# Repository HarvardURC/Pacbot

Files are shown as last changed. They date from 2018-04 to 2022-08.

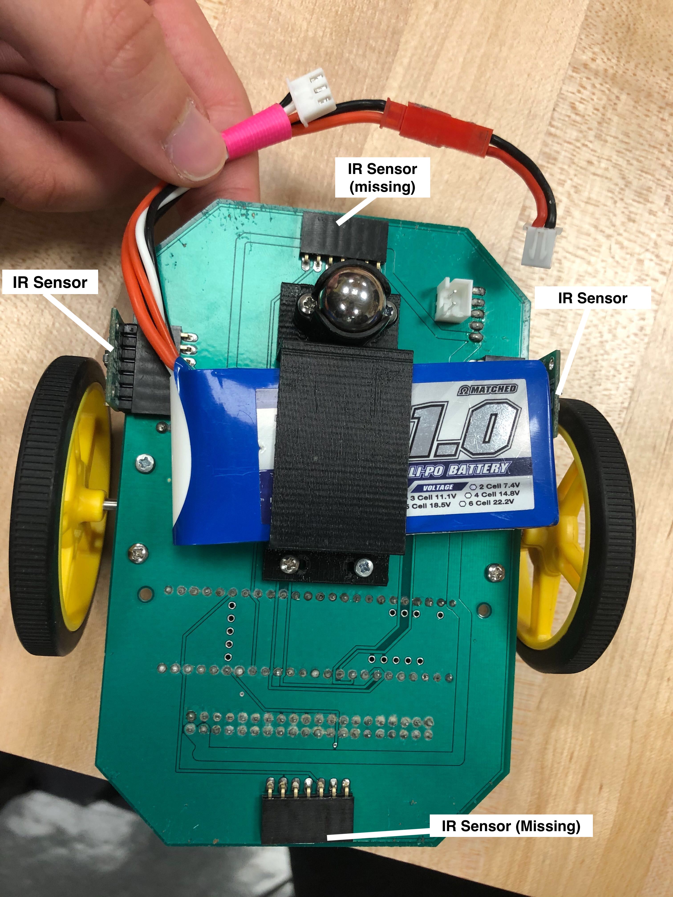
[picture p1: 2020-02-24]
docs/Public Designs/2018-19 Bot/bottomview.jpeg

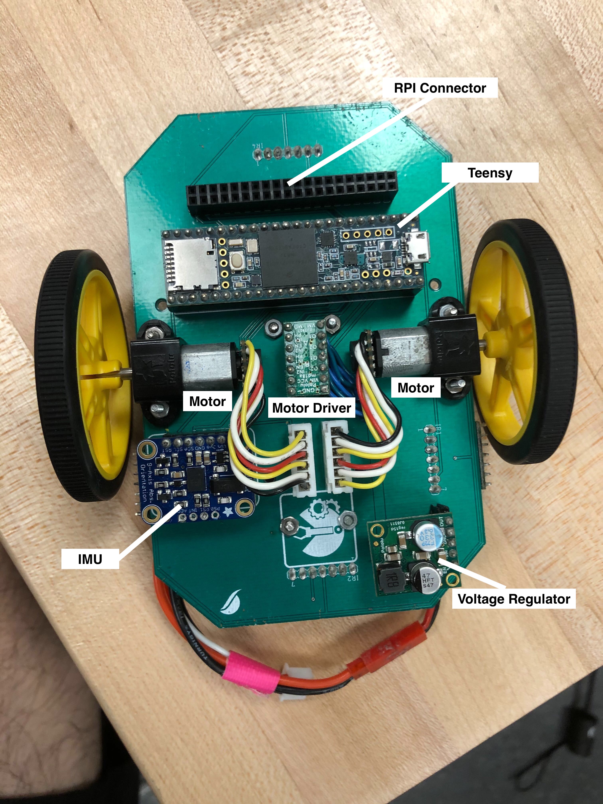
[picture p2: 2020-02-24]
docs/Public Designs/2018-19 Bot/topview.JPG

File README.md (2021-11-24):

# PacBot
Repository for the Harvard Undergraduate Robotics Club's PacBot team

> NOTE: Because this repository includes submodules, it should be cloned using `git clone --recursive`.

The rules for PacBot and helpful images can be found at our website: https://harvardrobotics.com/pacbots

Codebase for 2021-2022 can be found in the ***master*** branch. Codebases for past years can be found in their respective branches.

The current Pacman game code can be found in 'src/gameEngine'. The README there describes how to run the game.

The code for the Harvard robotics team's bot can be found in the 'src/botCode' folder (if you're looking for inspiration).

Documentation for participating teams regarding the game board/arena, bot designs from past years, and how to communicate with the game can be found in the 'docs' directory. Baseline code is provided here that teams can use to code their bots.

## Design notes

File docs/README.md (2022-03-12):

# PacBot Documentation

See 'A Guide to Connecting to the Game' for the step by step process to connect your robot to the PacMan game.

## Arena

'Arena Documentation' contains images of the life sized PacMan game board along with a SLDPRT file containg the CAD design of the arena. Overall, the arena mimics the PacMan game where each path is 7 inches wide. Bots should be smaller than 7 inches by 7 inches to effectively navigate the arena. The arena is currently made of wooden material, and the walls of the channels are painted white.

The arena is programmatically divided into a 28 x 31 grid. The ghost and PacBot locations are read out with respect to this grid. For details on the structure of this grid, 'src/gameEngine/pacbot/grid.py'.

## Sample Bot Code

The PacBot game uses WiFi to send the game state to participating robots; thus all participating teams must have WiFi compatible robots. To do this, PacBot uses Robomodules, a custom Python3 framework for handling communication between modular components using TCP traffic. The game uses a single Robomodules server; teams' bots will connect to this server to receive information about the Pacman game state. Specific documentation for Robomodules can be found here: https://github.com/HarvardURC/robomodules

To connect to the running game engine, teams must run their own Robomodules ProtoModule. The 'Sample BotCode' in this folder contains an example ProtoModule. Please see the 'Sample BotCode' for information regarding the ProtoModule and how it receives the game state.

## Public Designs

The 'Public Designs' folder contains information regarding the EE/ME design of last year's PacBot for the Harvard Undergraduate Robotics Club.

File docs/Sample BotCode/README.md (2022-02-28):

# Sample BotCode

## Files/Folders

### samplePacbotModule.py

This custom module is a subclass of the ProtoModule class from RoboModules. The module is initialized with a connection to the game engine server; the IP address of the game engine server host must be specified via the BIND_ADDRESS environment variable (or by changing the default in the code). Also, your bot must be on the same WiFi network as the game engine server to connect. Make sure this module is also connecting to the correct port the game engine server is listening on via the BIND_PORT environmental variable. 

When an instance of the module is running (by calling the run method), the method msg_received is called whenever the module receives a message from the game engine server. If the msg_type is MsgType.LIGHT_STATE, this message is the game state. This state contains the game state information (as outlined in the rules for the game). If desired, the tick function is helpful for running custom code at a desired frequency (in Hz). More details on how to use Robomodules in your own project if desired can be found in the Robomodules documentation (https://github.com/HarvardURC/robomodules).

### messages

This folder contains the Protobuf definitions of the messages your bot will be receiving. There is no need to edit this code.

### robomodules

Robomodules is a custom Python framework maintained by the Harvard Undergraduate Robotics Club that allows independent modular components to communicate via TCP traffic. The 'samplePacbotModule.py' is one module that communicates with the game engine, another module. No need to edit this code.

## Running the Sample Code

1. Run the game engine.
See 'src/gameEngine' for information. Essentially, one must run 'src/gameEngine/server.py' and 'src/gameEngine/gameEngine.py'.

2. Run 'samplePacbotModule.py'.
The state of the game should be printed on the screen. Make sure the BIND_ADDRESS environment variable is set to the IP address of the game engine server, and make sure the bot is connected to the same WiFi network as the server computer. This can also be run locally along with the game engine; just use the default BIND_ADDRESS of 'localhost'. Finally, make sure the BIND_PORT is the same port that the game engine server is listening on.

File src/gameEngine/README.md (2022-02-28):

# Pacbot 2021-22 gameEngine

## Requirements
To run the gameEngine, the dependencies listed in the ***src/environment.yml*** need to be installed. The ***src/environment.yml*** file is an exported Conda environment, so creating a Conda environment from this is recommended.

Currently, the game engine only runs on **Mac** and **Linux** computers (not Windows). We are working on fixing issues with the Python graphics package to allow the game engine to run on Windows computers.

## Running the gameEngine

To run the gameEngine, first run the server and then run each of the module proccesses separately. 

Specifically, run the following files:

1. `./server.py`
This creates a server for communicating between the different modules. The modules that run the game connect to this server. In addition, the PacBot will connect to this server to receive the game state. The server automatically binds to 'localhost' for testing purposes, but should be bound to the computer's local IP address when attempting to communicate with the robot over WiFi. Set the environment variable BIND_ADDRESS to control the IP address of the server. In addition, a different port may be needed than the default; set the environment variable BIND_PORT to control this as well.

2. `./gameEngine.py`
This runs the game. Type r to restart, p to unpause/pause, and q to quit.

3. `./visualize.py` OR `./terminalPrinter.py`

*visualize.py* displays the game graphics - see **Visualizer** for info regarding its command line arguments.

*terminalPrinter.py* will instead display the game in the terminal.

4. `./keyboardInput.py` OR `./cameraReader.py`

*keyboardInput.py* allows you to provide w,a,s,d commands for moving the PacBot (you must be in this terminal window to provide these commands).

*cameraReader.py* will instead use the connected cameras to track where the PacBot is on the game board and relay that information to the gameEngine.

## Visualizer

The visualizer takes 3 command line arguments:
- `-w` - If this is supplied, then the visualizer will draw the maze walls.
- `-p` - If this is supplied, then the visualizer will draw pacman.
- `-s` - If this is supplied, then the visualizer should fit the entire game onto your computer screen. 
         If not, then you can supply a specific square size by inputting `-s=x`, where x is some integer.
         Default square size without `-s` is 31, square size with `-s` is 25.

## KeyboardInput

When running the keyboard input, you can move pacman using the w,a,s,d keys.

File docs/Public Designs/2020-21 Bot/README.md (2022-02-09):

# Harvard PacBot Design Overview 2020-21
PCB design files and images of the bot can be found in this directory.

## Electrical Components
-1 Raspberry Pi Zero W

-1 Teensy 3.5

-1 PCB

-1 IMU (not in images)

-4 IR Sensors

-2 Magnetic encoder pairs

-2 Motors

-1 Motor Driver

-Li-Po Battery

-1 voltage regulator

(specific links to components can be found at https://docs.google.com/spreadsheets/d/1ZO9OBoGcNkOdx6GaBkAFo6AWodeVCOaCXKic-0er2z0/edit?usp=sharing)

## Mechanical Components
-Wheels/Ball Casters

## Broad Overview
### Sensors

IR sensors are used for detecting whether we are near walls. These are placed on the sides and the front/back of the bot (see photos). Past robots used PID control on these sensors to follow the walls.

Magnetic encoders are attached to the motors to track the amount of distance we travel.

An IMU was intended to be used for general navigation of the robot (to ensure we don't hit walls and turn accurately - other uses are possible). It's not present in the photos.

### Processors

A Raspberry Pi Zero W is used to interface with the motors (through the motor driver) and the IR sensors. It also connects to our local wifi network in order to receive instructions from a computer regarding where the bot should travel (the high level code would run on a remote computer and send commands to the PacBot).

Because of the encoder's output requirements, a Teensy is used to receive the encoder readings. The Teensy is also connected to the IMU. The Teensy communicates these sensor readings to the Raspberry Pi via serial communication.

### Motors

Two medium power, 6V, brushed DC gear motors are used on our bot (see https://www.pololu.com/product/2381). A motor driver is necessary to communicate with the motors from the Raspberry Pi. The encoders are attached to the motors.

### PCB

All of our electrical components are connected via a Printed Circuit Board. This is the main "structure" of our bot; all components are soldered onto this. The KiCad files for the PCB can be found in this directory.

### Code

All of the code for our bot (high level and low level) can be found in the *src/botCode* directory of this GitHub repo.

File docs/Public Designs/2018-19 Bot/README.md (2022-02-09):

# Harvard PacBot Design Overview 2018-19
(PCB design files and schematic can be found in public PacBot Design Folder)

## Electrical Components
-1 Raspberry Pi Zero W

-1 Teensy 3.5

-1 PCB

-1 IMU

-Assorted capacitors, resistors, wires

-4 IR Sensors

-2 Magnetic encoder pairs

-2 Motors

-1 Motor Driver

-Li-Po Battery

(specific links to components can be found at https://docs.google.com/spreadsheets/d/1ZO9OBoGcNkOdx6GaBkAFo6AWodeVCOaCXKic-0er2z0/edit?usp=sharing)

## Mechanical Components
-Wheels/Ball Casters

-3D Printed Battery Clip

## Code
All code can be found in the accompanying folders in this repo. We recommend looking at code from 2018-2019 because this year's code will be undergoing maintenance between now and the competition.

## Broad Overview
As the core processors for the bot, a Raspberry Pi Zero W and Teensy 3.5 were used. Nearly all of our high level and low level code ran off of our Raspberry Pi Zero W; the teensy was mainly used to interface with the encoders and other sensors. The entire bot was centered around the PCB. The motors directly attached to the PCB using small brackets, and all of the electrical components were soldered on in some manner. Although the schematic of the electrical components and the PCB design (which are in this folder) give an idea of the set up of our bot, we unfortunately do not have a SolidWorks design of our 2018-19 bot. A few photos of the 2018-19 bot in this folder help give a picture of the overall design.

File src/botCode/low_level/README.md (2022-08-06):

# Overview of Low Level Code

## teensy_code

This contains code for the teensy. The final code running on the teensy was `teensy_code/sensors/sensors.ino`. Make sure to fulfill the requirements in the requirements.txt file if loading to the teensy. Also, if you're loading this to the teensy on the 2021-2022 bot, you'll need to modify your Teensy Wire library such that Wire1 is defined. Specifically, uncomment `#define WIRE_IMPLEMENT_WIRE1` in WireKinetis.h.

I recommend using TeensyDuino with the teensy. I think these instructions are alright for Teensy: https://www.pjrc.com/teensy/td_usage.html. With the Arduino IDE, make sure you have the correct Board and Port selected under Tools. Also, to load a sketch onto the Teensy, you only need to press the Compile button and the button on the Teensy. DON'T press the Arduino IDE Upload button.

## motors.py

motors.py controls the motors. It uses PIDs of the IMU to turn to the direction we want to go and go straight. directionLowLevelModule.py tells this what direction to take our robot.

## sensors.py and tofSensor.py

These are for controlling our IR sensors.

## teensySensors.py

This is for reading from the serial port to get the Encoder and IMU measurements from the Teensy.

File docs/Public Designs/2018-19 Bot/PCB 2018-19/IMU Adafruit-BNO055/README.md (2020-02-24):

# Adafruit-BNO055-Breakout-PCB
PCB files for the BNO055 Breakout

Format is EagleCAD schematic and board layout

For more details, check out the product page at

    * https://www.adafruit.com/product/2472

Adafruit invests time and resources providing this open source design, 
please support Adafruit and open-source hardware by purchasing 
products from Adafruit!

Designed by Adafruit Industries.  
Creative Commons Attribution, Share-Alike license, check license.txt for more information
All text above must be included in any redistribution

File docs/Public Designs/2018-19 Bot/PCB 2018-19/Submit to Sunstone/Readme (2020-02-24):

LAYER DESCRIPTIONS

tplace (21), tnames (25): Top silk layer

bplace (22), bnames (26): Bottom silk layer

holes (45): Reference for where holes should be placed so that PCB can be fastened by nut and bolt

reference (49): For personal reference (not to be printed)

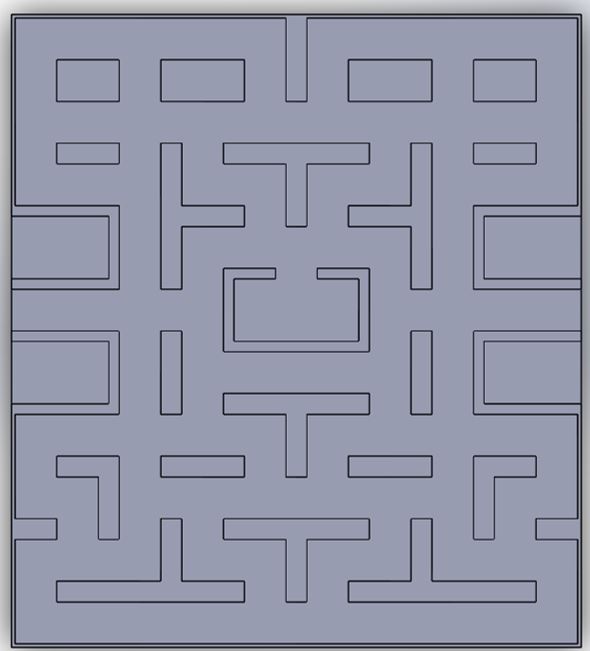
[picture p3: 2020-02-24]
docs/Arena Documentation/Pacbot arena.JPG

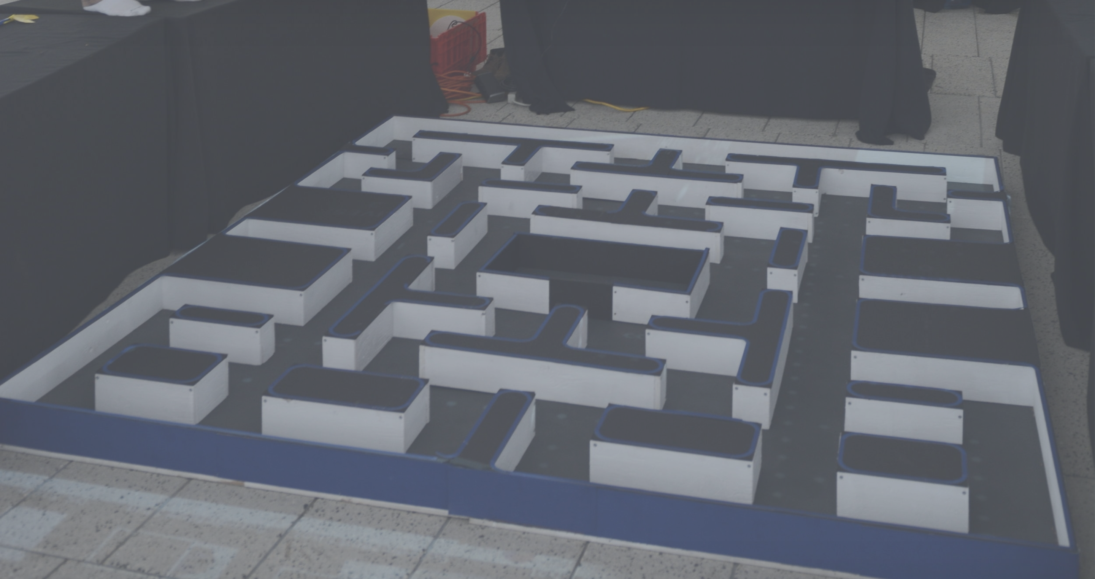
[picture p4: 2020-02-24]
docs/Arena Documentation/arena_side_view.png

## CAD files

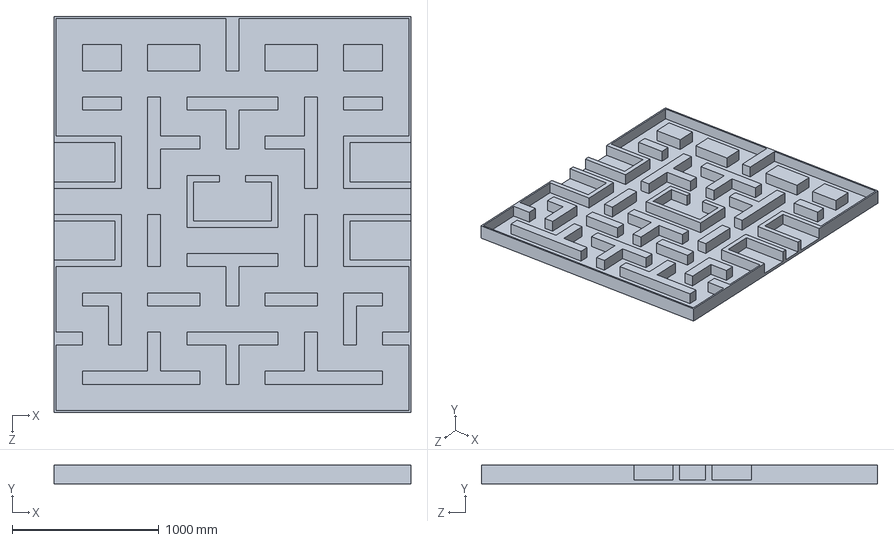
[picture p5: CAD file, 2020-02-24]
docs/Arena Documentation/1classic_arena_pacbot.SLDPRT
2429.9 x 127.0 x 2696.6 mm

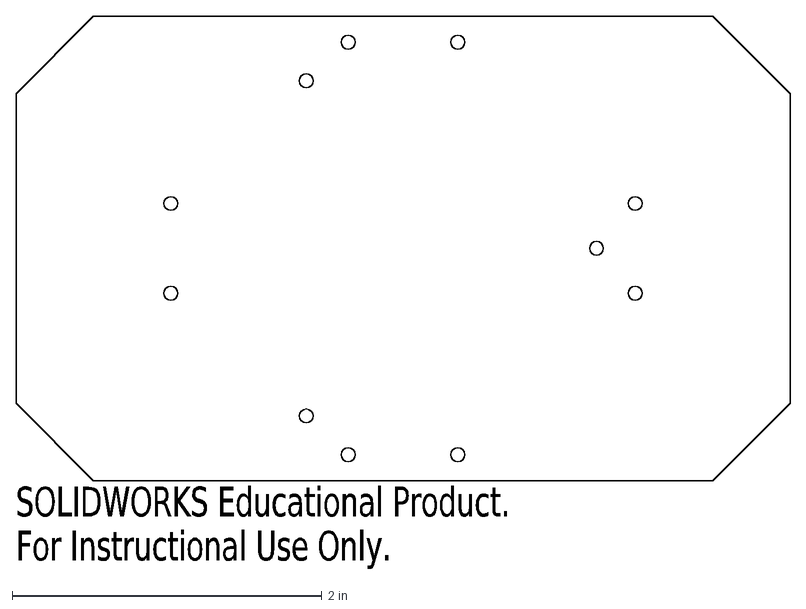
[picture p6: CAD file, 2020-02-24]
docs/Public Designs/2020-21 Bot/PCB/graphics/PacbotPCB.DXF
SOLIDWORKS Educational Product.
For Instructional Use Only.

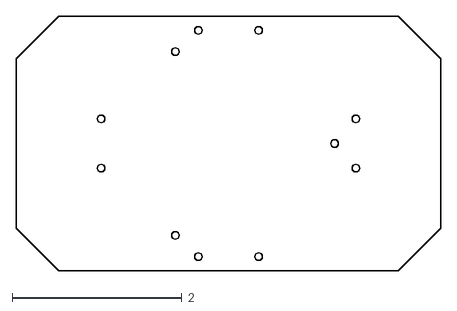
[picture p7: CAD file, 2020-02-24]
docs/Public Designs/2020-21 Bot/PCB/graphics/PacBot_board_outline.dxf
5.00 x 3.00

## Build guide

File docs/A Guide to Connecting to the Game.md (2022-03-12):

# How to run the game and connect to your bot - A Guide

This guide outlines the step by step process for running the PacMan game and connecting your robot to the game.

1. Ensure you have the necessary Python libraries installed as outlined in 'src/requirements.txt'. We recommend using a Conda environment; an image of our environment is provided in 'src/evironment.yml'.

2. Ensure your robot and computer (that's running the PacMan game) are on the same WiFi network.

3. Set the bind address for the PacMan game server.

The computer running the game will have a server that forwards messages about the game state to your robot. The bind address for this server should be the local IP address of your game computer.

Set the bind address via ```export BIND_ADDRESS=myIpAddress``` where ```myIpAddress``` is the local IP address of your game computer. Run this command in your shell on the game computer and on your robot.

4. Run the game on your computer.

Follow the instructions on 'src/gameEngine'. You should specifically run 'src/gameEngine/server.py', 'src/gameEngine/gameEngine.py', and 'src/gameEngine/visualize.py'.

5. Run the sample botcode on your robot.

Run 'docs/Sample BotCode/samplePacbotModule.py' on your robot. The state of the game should be printed.

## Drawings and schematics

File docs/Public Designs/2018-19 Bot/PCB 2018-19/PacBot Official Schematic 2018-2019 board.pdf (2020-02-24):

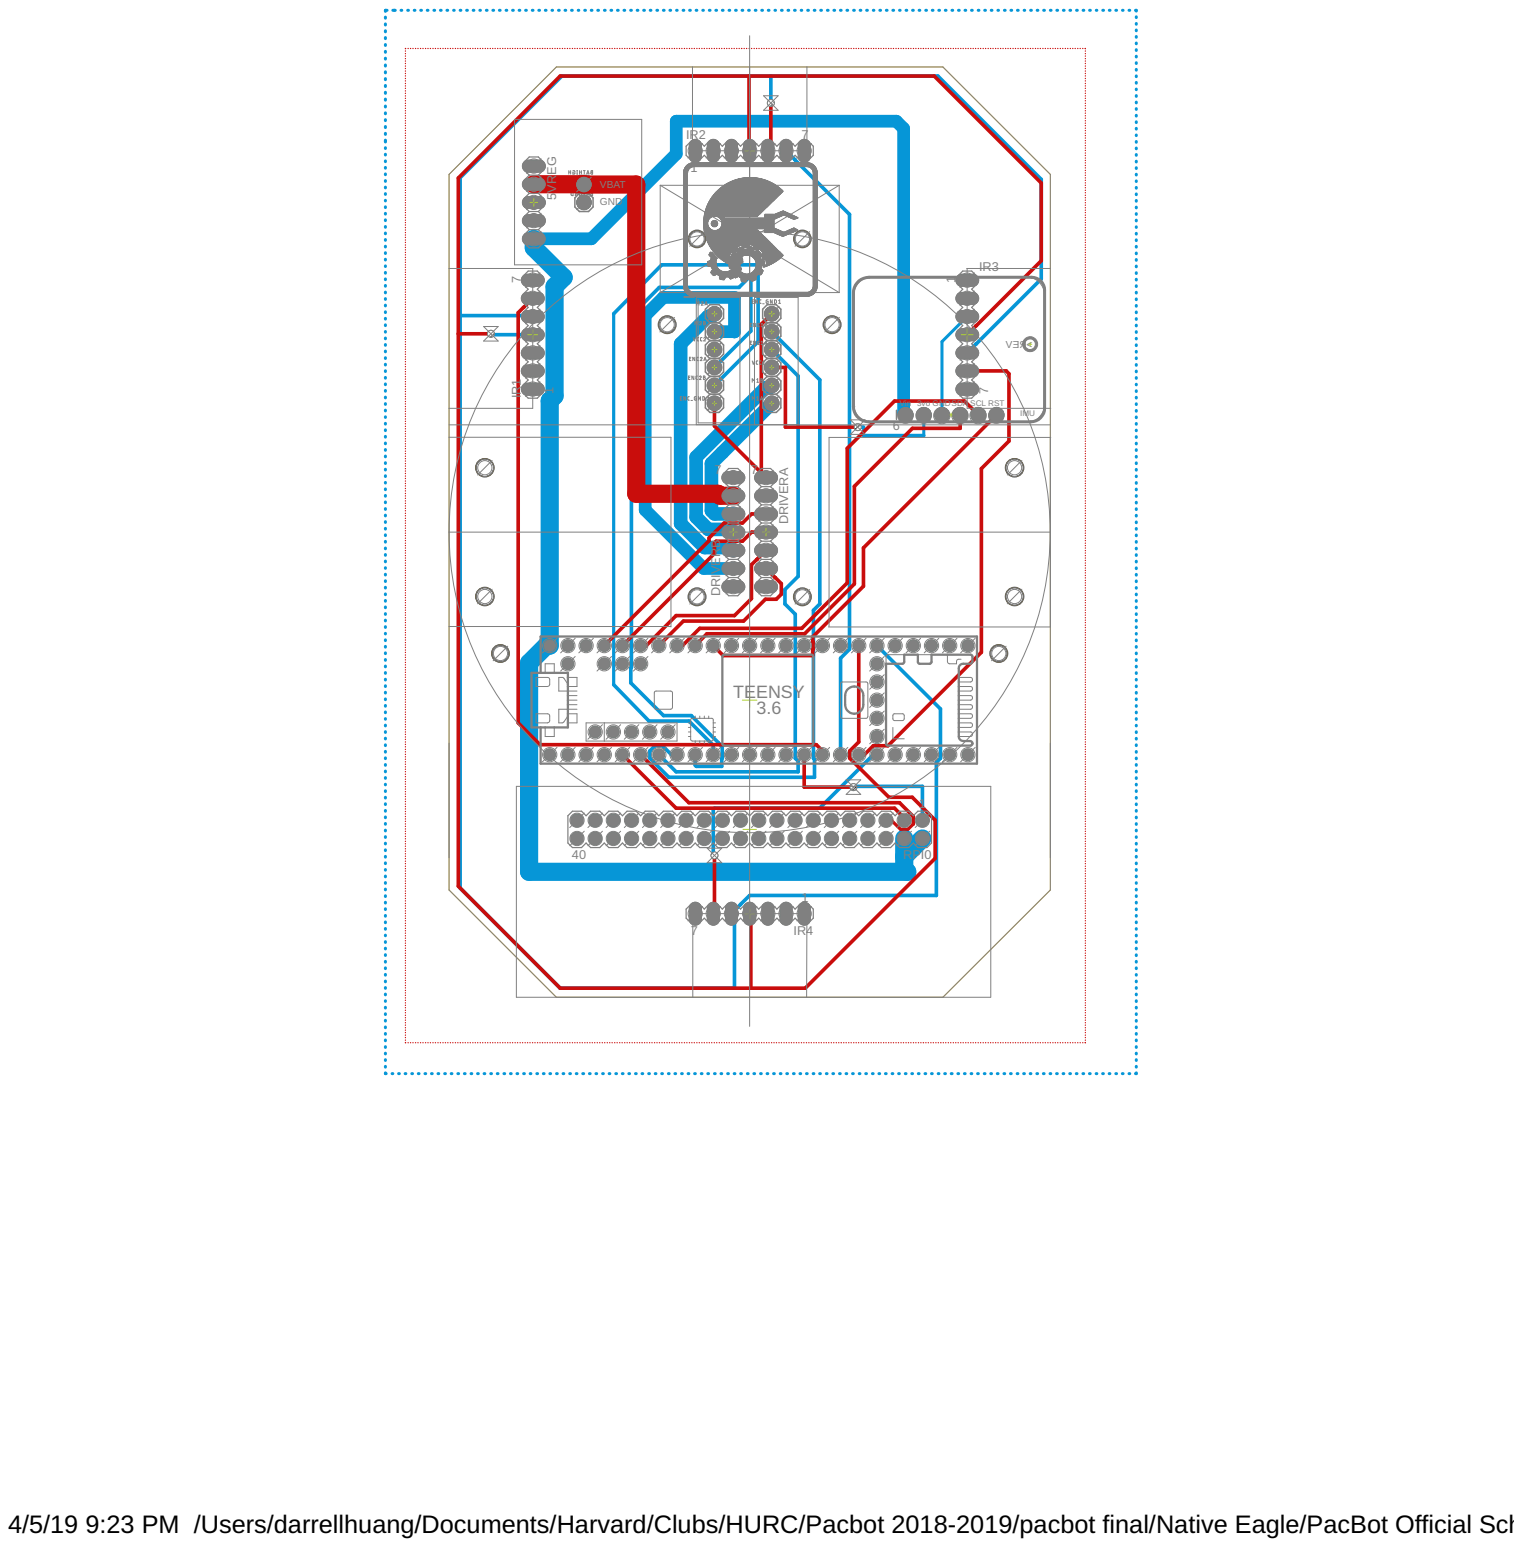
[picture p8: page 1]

Vin 3vo GNDSDA SCL RST 1

4/5/19 9:23 PM /Users/darrellhuang/Documents/Harvard/Clubs/HURC/Pacbot 2018-2019/pacbot final/Native Eagle/PacBot Official Schematic 2018-2019.brd

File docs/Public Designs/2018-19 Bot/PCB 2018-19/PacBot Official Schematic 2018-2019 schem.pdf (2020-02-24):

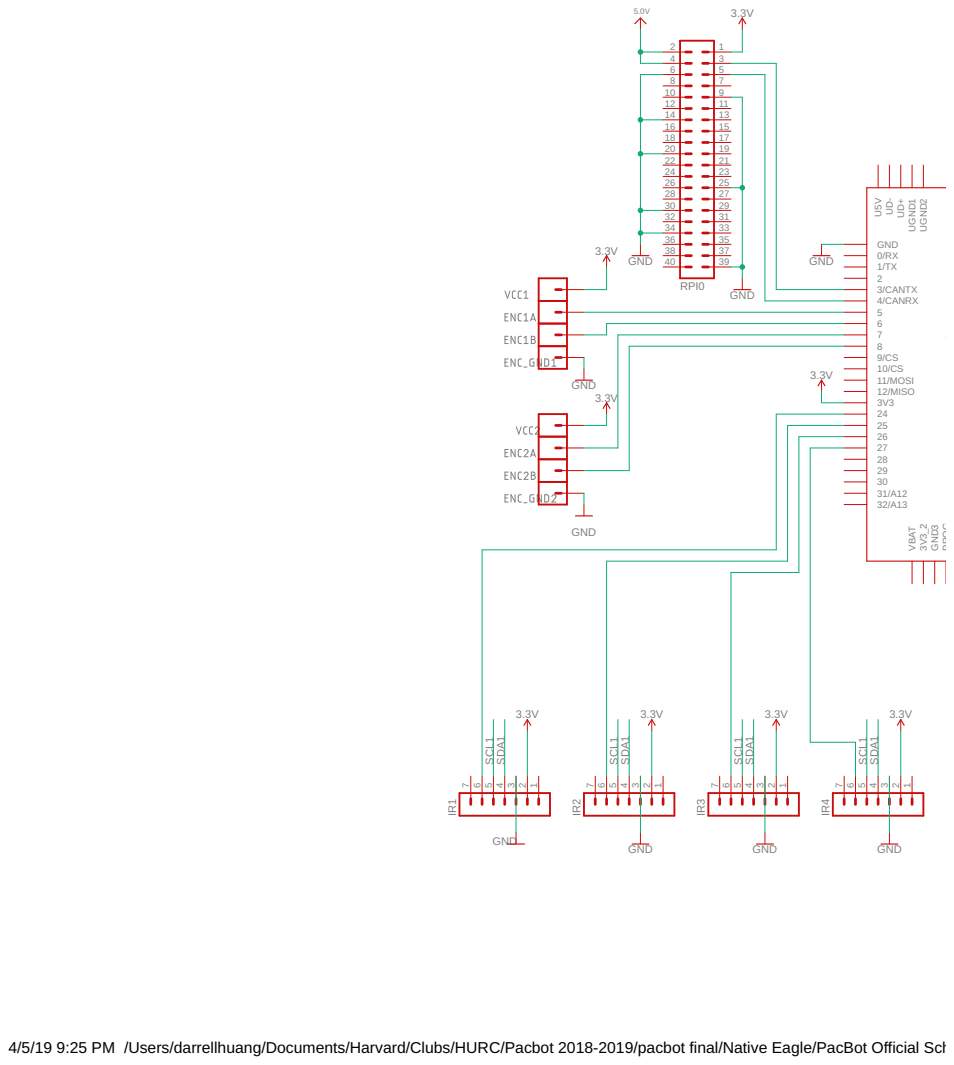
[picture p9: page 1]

4/5/19 9:25 PM /Users/darrellhuang/Documents/Harvard/Clubs/HURC/Pacbot 2018-2019/pacbot final/Native Eagle/PacBot Official Schematic 2018-2019.sch (Sheet: 1/1)

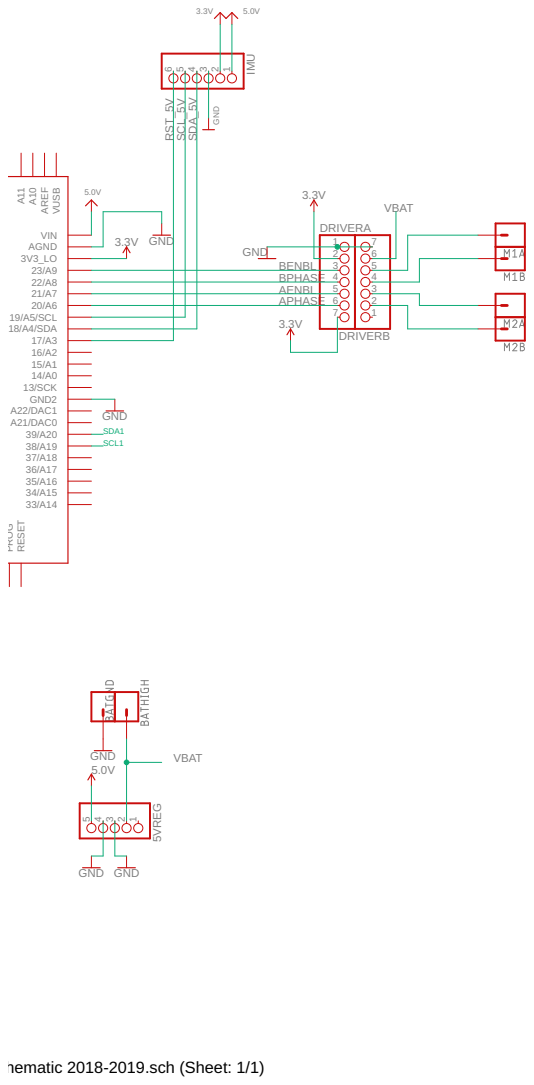
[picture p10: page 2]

BPHASE | 4
AENBL | 5
APHASE | 6

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

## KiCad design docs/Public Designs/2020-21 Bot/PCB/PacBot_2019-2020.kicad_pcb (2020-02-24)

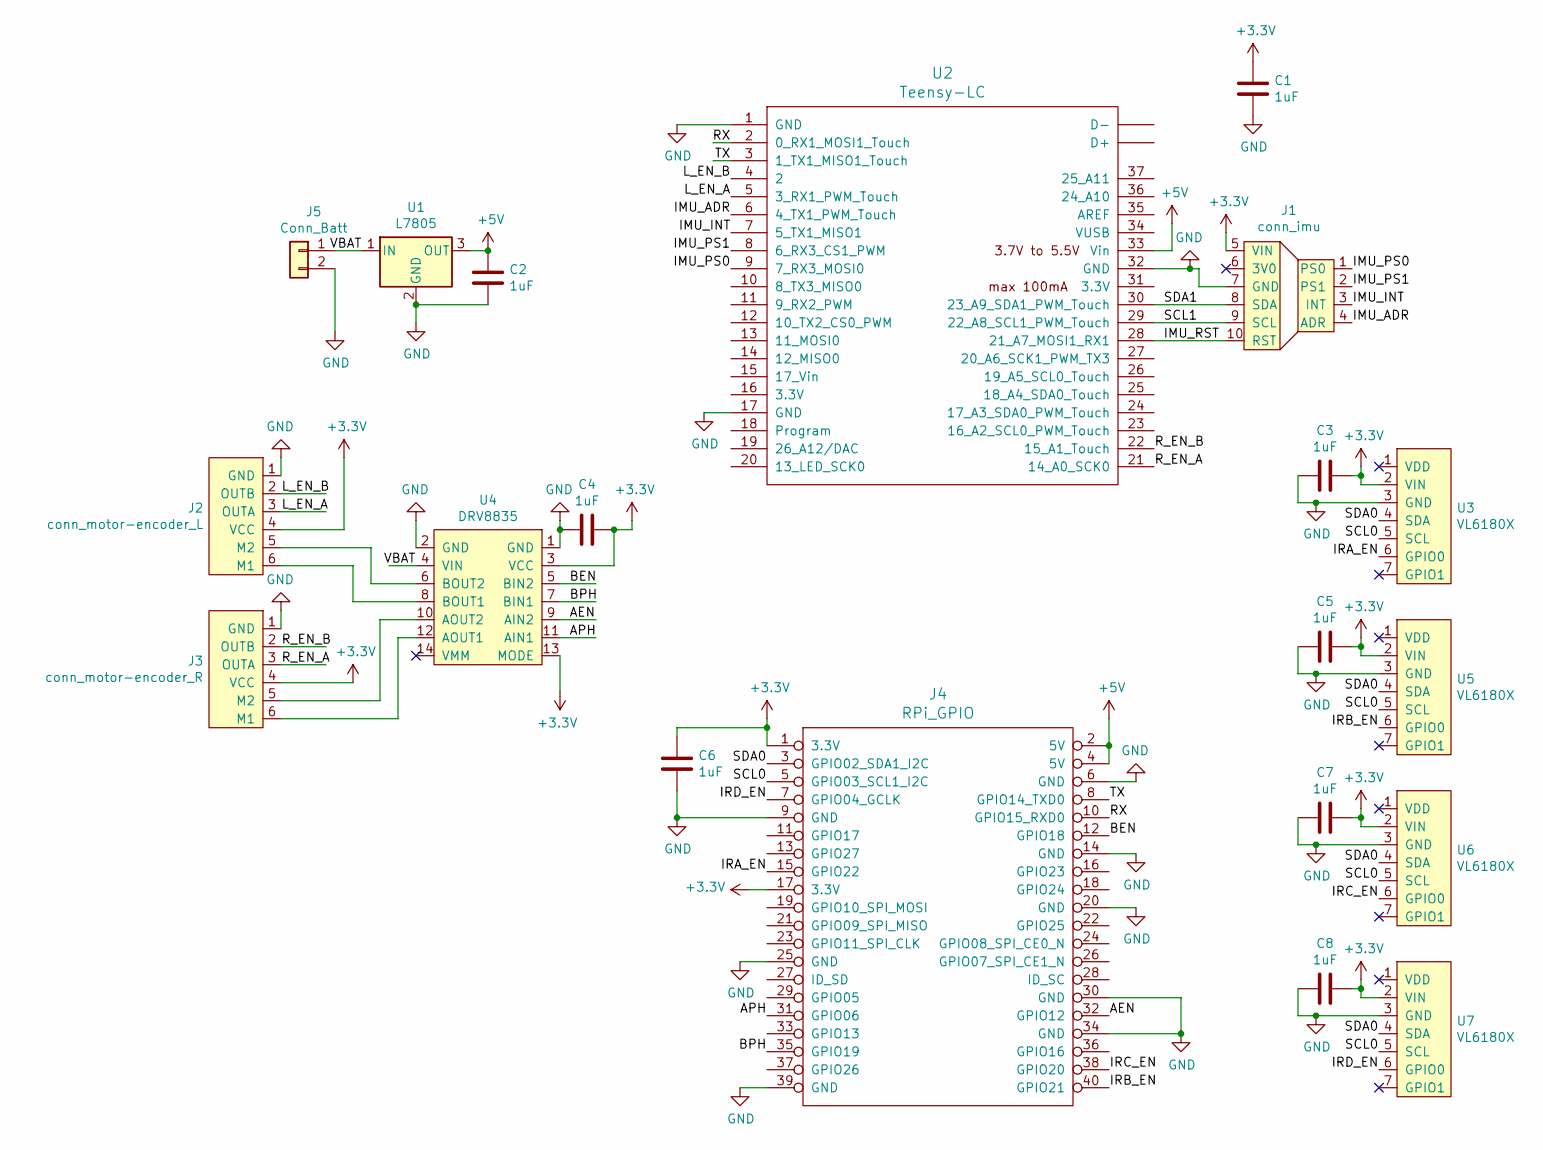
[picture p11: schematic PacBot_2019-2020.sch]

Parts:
C1, C2, C3, C4, C5, C6, C7, C8: 1uF; C_0603_1608Metric
J1: conn_imu
J2: conn_motor-encoder_L; JST_PH_B6B-PH-K_1x06_P2.00mm_Vertical
J3: conn_motor-encoder_R; JST_PH_B6B-PH-K_1x06_P2.00mm_Vertical
J4: RPi_GPIO; ADA3708_RPI-ZERO
J5: Conn_Batt; JST_PH_B2B-PH-K_1x02_P2.00mm_Vertical
U1: L7805; Stocko_MKS_1653-6-0-303_1x3_P2.50mm_Vertical
U2: Teensy-LC; Teensy30_31_32_LC
U3, U5, U6, U7: VL6180X; conn_ir
U4: DRV8835; drv8835

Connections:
+3V3: C1.1, C3.2, C4.1, C5.1, C6.1, C7.1, C8.1, J1.5 (VIN), J2.4 (VCC), J3.4 (VCC), J4.1 (3.3V), J4.17 (3.3V), U3.2 (VIN), U4.3 (VCC), U4.13 (MODE), U5.2 (VIN), U6.2 (VIN), U7.2 (VIN)
+5V: C2.1, J4.2 (5V), J4.4 (5V), U1.3 (OUT), U2.33 (Vin)
/AEN: J4.32 (GPIO12), U4.9 (AIN2)
/APH: J4.31 (GPIO06), U4.11 (AIN1)
/BEN: J4.12 (GPIO18), U4.5 (BIN2)
/BPH: J4.35 (GPIO19), U4.7 (BIN1)
/IMU_ADR: J1.4 (ADR), U2.6 (4_TX1_PWM_Touch)
/IMU_INT: J1.3 (INT), U2.7 (5_TX1_MISO1)
/IMU_PS0: J1.1 (PS0), U2.9 (7_RX3_MOSI0)
/IMU_PS1: J1.2 (PS1), U2.8 (6_RX3_CS1_PWM)
/IMU_RST: J1.10 (RST), U2.28 (21_A7_MOSI1_RX1)
/IRA_EN: J4.15 (GPIO22), U3.6 (GPIO0)
/IRB_EN: J4.40 (GPIO21), U5.6 (GPIO0)
/IRC_EN: J4.38 (GPIO20), U6.6 (GPIO0)
/IRD_EN: J4.7 (GPIO04_GCLK), U7.6 (GPIO0)
/L_EN_A: J2.3 (OUTA), U2.5 (3_RX1_PWM_Touch)
/L_EN_B: J2.2 (OUTB), U2.4 (2)
/RX: J4.10 (GPIO15_RXD0), U2.2 (0_RX1_MOSI1_Touch)
/R_EN_A: J3.3 (OUTA), U2.21 (14_A0_SCK0)
/R_EN_B: J3.2 (OUTB), U2.22 (15_A1_Touch)
/SCL0: J4.5 (GPIO03_SCL1_I2C), U3.5 (SCL), U5.5 (SCL), U6.5 (SCL), U7.5 (SCL)
/SCL1: J1.9 (SCL), U2.29 (22_A8_SCL1_PWM_Touch)
/SDA0: J4.3 (GPIO02_SDA1_I2C), U3.4 (SDA), U5.4 (SDA), U6.4 (SDA), U7.4 (SDA)
/SDA1: J1.8 (SDA), U2.30 (23_A9_SDA1_PWM_Touch)
/TX: J4.8 (GPIO14_TXD0), U2.3 (1_TX1_MISO1_Touch)
/VBAT: J5.1, U1.1 (IN), U4.4 (VIN)
GND: C1.2, C2.2, C3.1, C4.2, C5.2, C6.2, C7.2, C8.2, J1.7 (GND), J2.1 (GND), J3.1 (GND), J4.6 (GND), J4.9 (GND), J4.14 (GND), J4.20 (GND), J4.25 (GND), J4.30 (GND), J4.34 (GND), J4.39 (GND), J5.2, U1.2 (GND), U2.1 (GND), U2.17 (GND), U2.32 (GND), U3.3 (GND), U4.1 (GND), U4.2 (GND), U5.3 (GND), U6.3 (GND), U7.3 (GND)
unnamed: J2.5 (M2), U4.6 (BOUT2)
unnamed: J2.6 (M1), U4.8 (BOUT1)
unnamed: J3.5 (M2), U4.10 (AOUT2)
unnamed: J3.6 (M1), U4.12 (AOUT1)

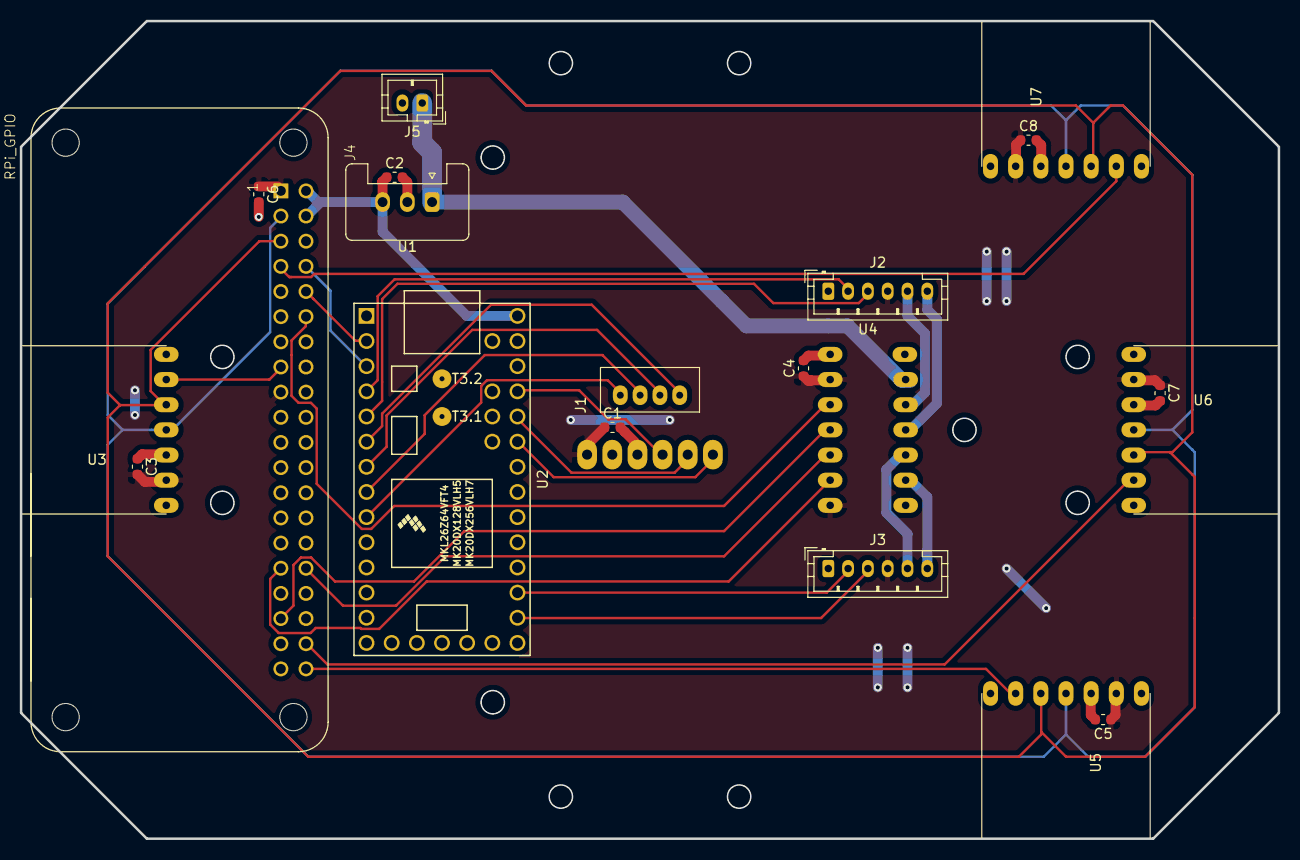
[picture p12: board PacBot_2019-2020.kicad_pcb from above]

Board: 2 copper layers, 127.0 x 82.6 mm, 20 parts (0 on the bottom side), 31 nets.

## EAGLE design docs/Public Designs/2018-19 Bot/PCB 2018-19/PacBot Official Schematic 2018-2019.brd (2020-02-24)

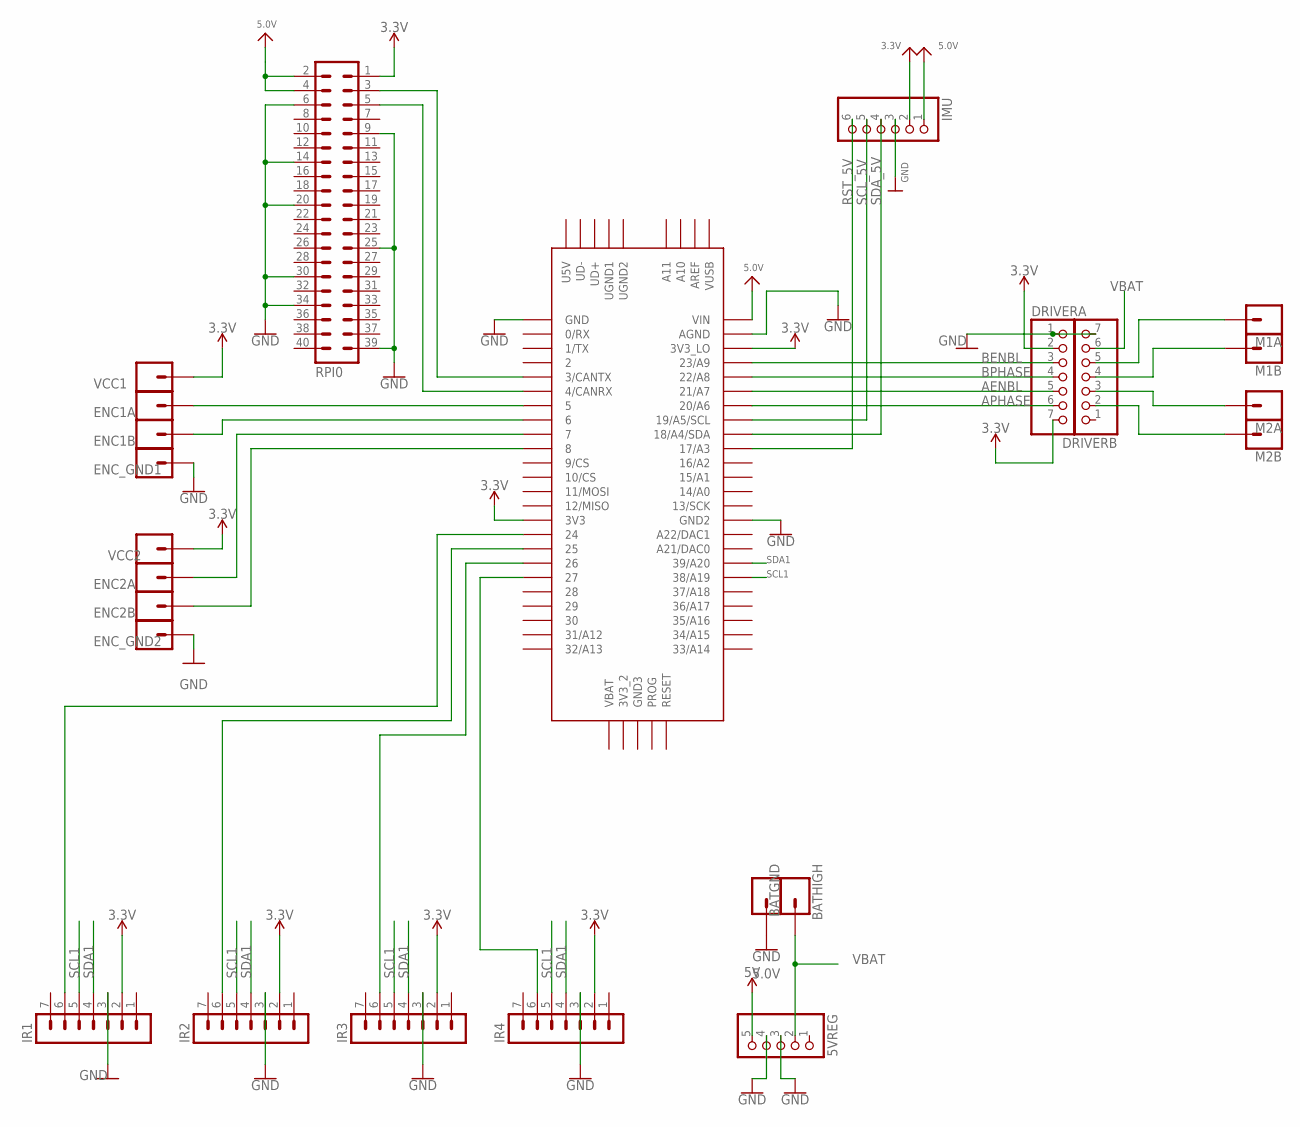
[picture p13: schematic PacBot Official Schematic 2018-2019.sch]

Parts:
5VREG: PINHD-1X5; 1X05
BATGND: CONN_01; 1X01
BATHIGH: CONN_01; 1X01
DRIVERA: PINHD-1X7; 1X07
DRIVERB: PINHD-1X7; 1X07
ENC1A, ENC1B, ENC2A, ENC2B: CONN_01; 1X01
ENC_GND1, ENC_GND2: CONN_01; 1X01
IMU: HEADER-1X676MIL; 1X06_ROUND_76
IR1, IR2, IR3, IR4: MA07-1
M1A, M1B, M2A, M2B: CONN_01; 1X01
RPI0: MA20-2
U$1: TEENSY_3.5/3.6
VCC1, VCC2: CONN_01; 1X01

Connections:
3.3V: DRIVERA.2, DRIVERA.7, IMU.2, IR1.2, IR2.2, IR3.2, IR4.2, RPI0.1, U$1.3V3, U$1.3V3_LO, VCC1.1, VCC2.1
5.0V: 5VREG.5, IMU.1, RPI0.2, RPI0.4, U$1.VIN
AENBL: DRIVERA.5, U$1.21/A7
APHASE: DRIVERA.6, U$1.20/A6
BENBL: DRIVERA.3, U$1.23/A9
BPHASE: DRIVERA.4, U$1.22/A8
GND: 5VREG.3, 5VREG.4, BATGND.1, DRIVERA.1, DRIVERB.7, ENC_GND1.1, ENC_GND2.1, IMU.3, IR1.3, IR2.3, IR3.3, IR4.3, RPI0.6, RPI0.9, RPI0.14, RPI0.20, RPI0.25, RPI0.30, RPI0.34, RPI0.39, U$1.AGND, U$1.GND, U$1.GND2
unnamed: ENC1A.1, U$1.5
unnamed: IR2.6, U$1.25
unnamed: RPI0.3, U$1.3/CANTX
unnamed: IR3.6, U$1.26
unnamed: ENC1B.1, U$1.6
unnamed: RPI0.5, U$1.4/CANRX
unnamed: IR4.6, U$1.27
unnamed: DRIVERB.5, M1A.1
unnamed: DRIVERB.4, M1B.1
unnamed: DRIVERB.3, M2A.1
unnamed: DRIVERB.2, M2B.1
unnamed: ENC2A.1, U$1.7
unnamed: ENC2B.1, U$1.8
unnamed: IR1.6, U$1.24
RST_5V: IMU.6, U$1.17/A3
SCL1: IR1.5, IR2.5, IR3.5, IR4.5, U$1.38/A19
SCL_5V: IMU.5, U$1.19/A5/SCL
SDA1: IR1.4, IR2.4, IR3.4, IR4.4, U$1.39/A20
SDA_5V: IMU.4, U$1.18/A4/SDA
VBAT: 5VREG.2, BATHIGH.1, DRIVERB.6

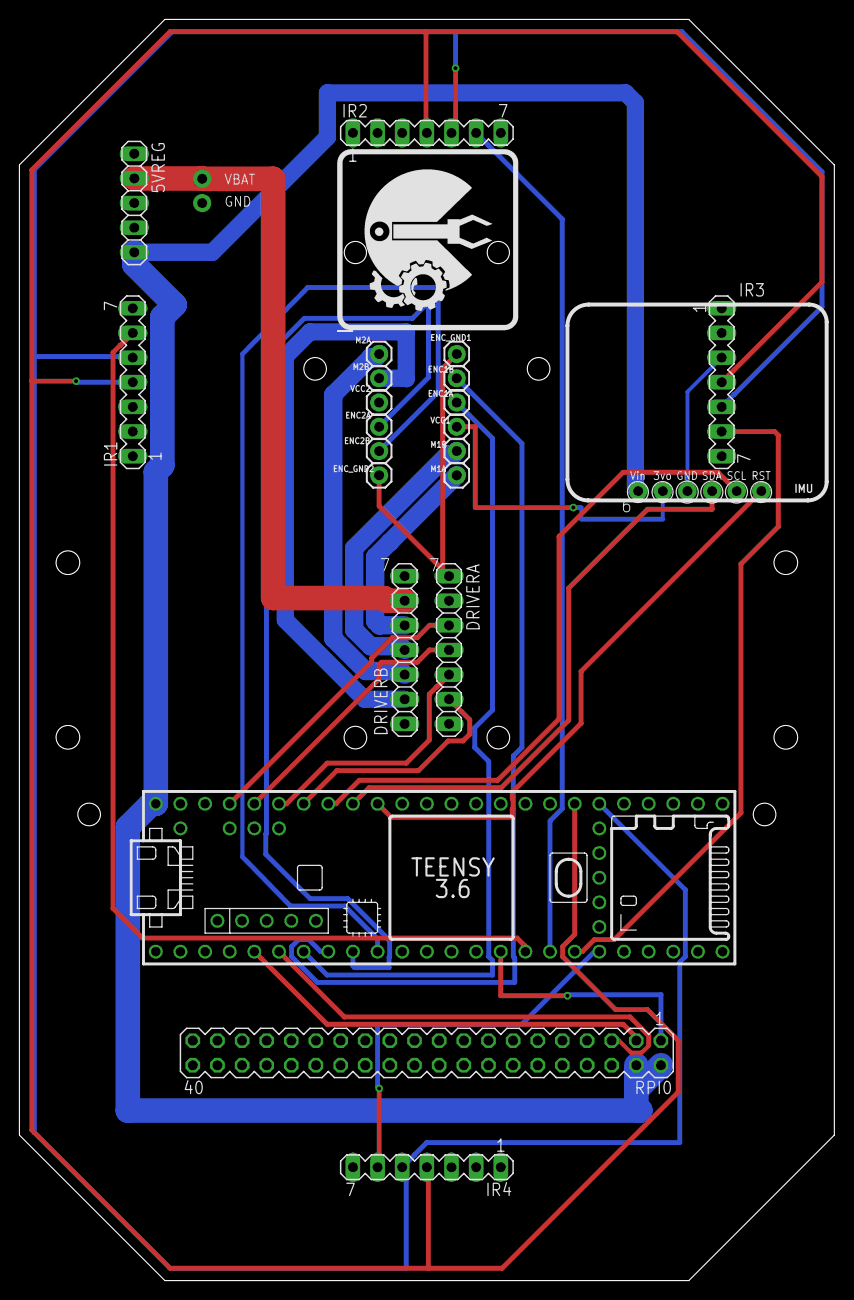
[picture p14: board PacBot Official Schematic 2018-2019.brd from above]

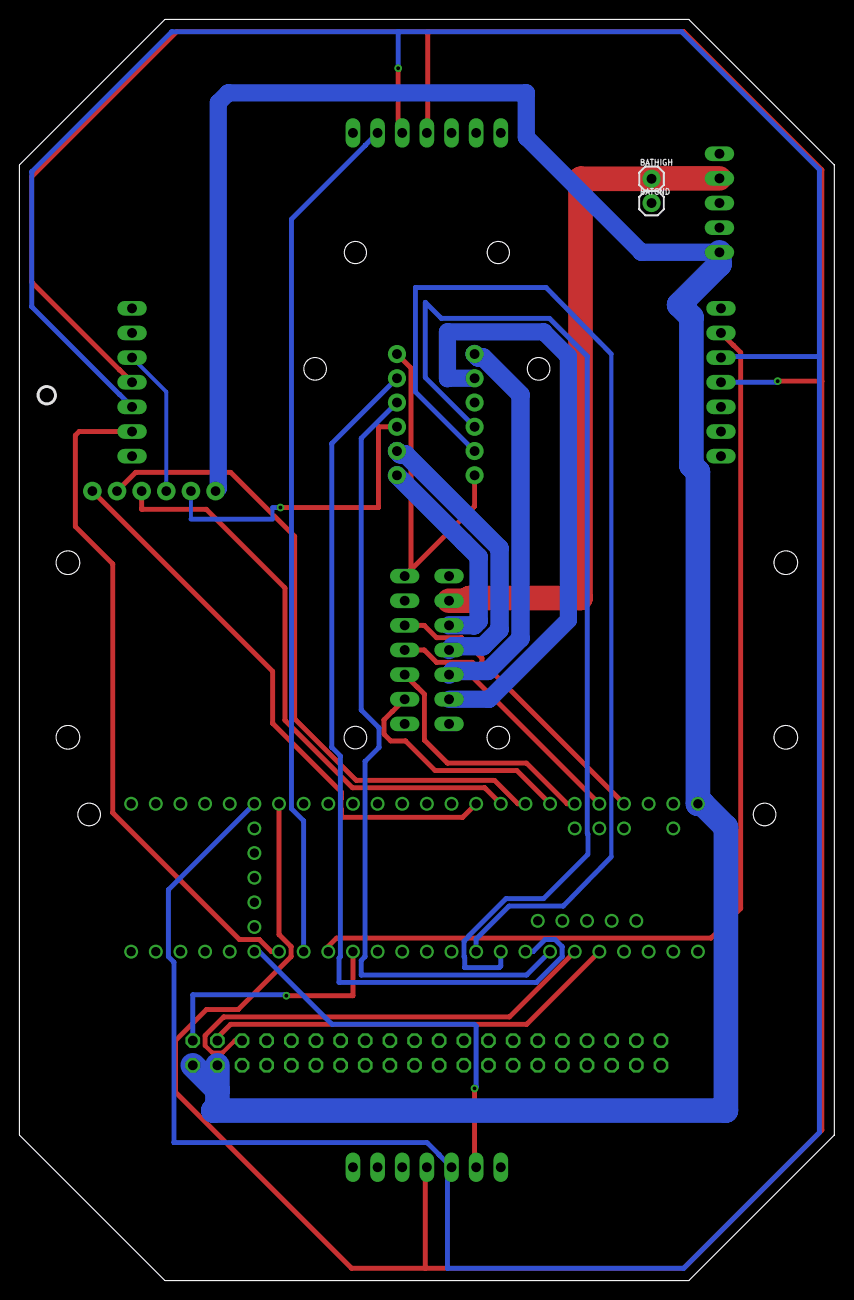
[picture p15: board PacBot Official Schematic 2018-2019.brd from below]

Board: 2 copper layers, 84.0 x 130.0 mm, 25 parts (3 on the bottom side), 27 nets.

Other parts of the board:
U$65: PCBFEAT-REV-040

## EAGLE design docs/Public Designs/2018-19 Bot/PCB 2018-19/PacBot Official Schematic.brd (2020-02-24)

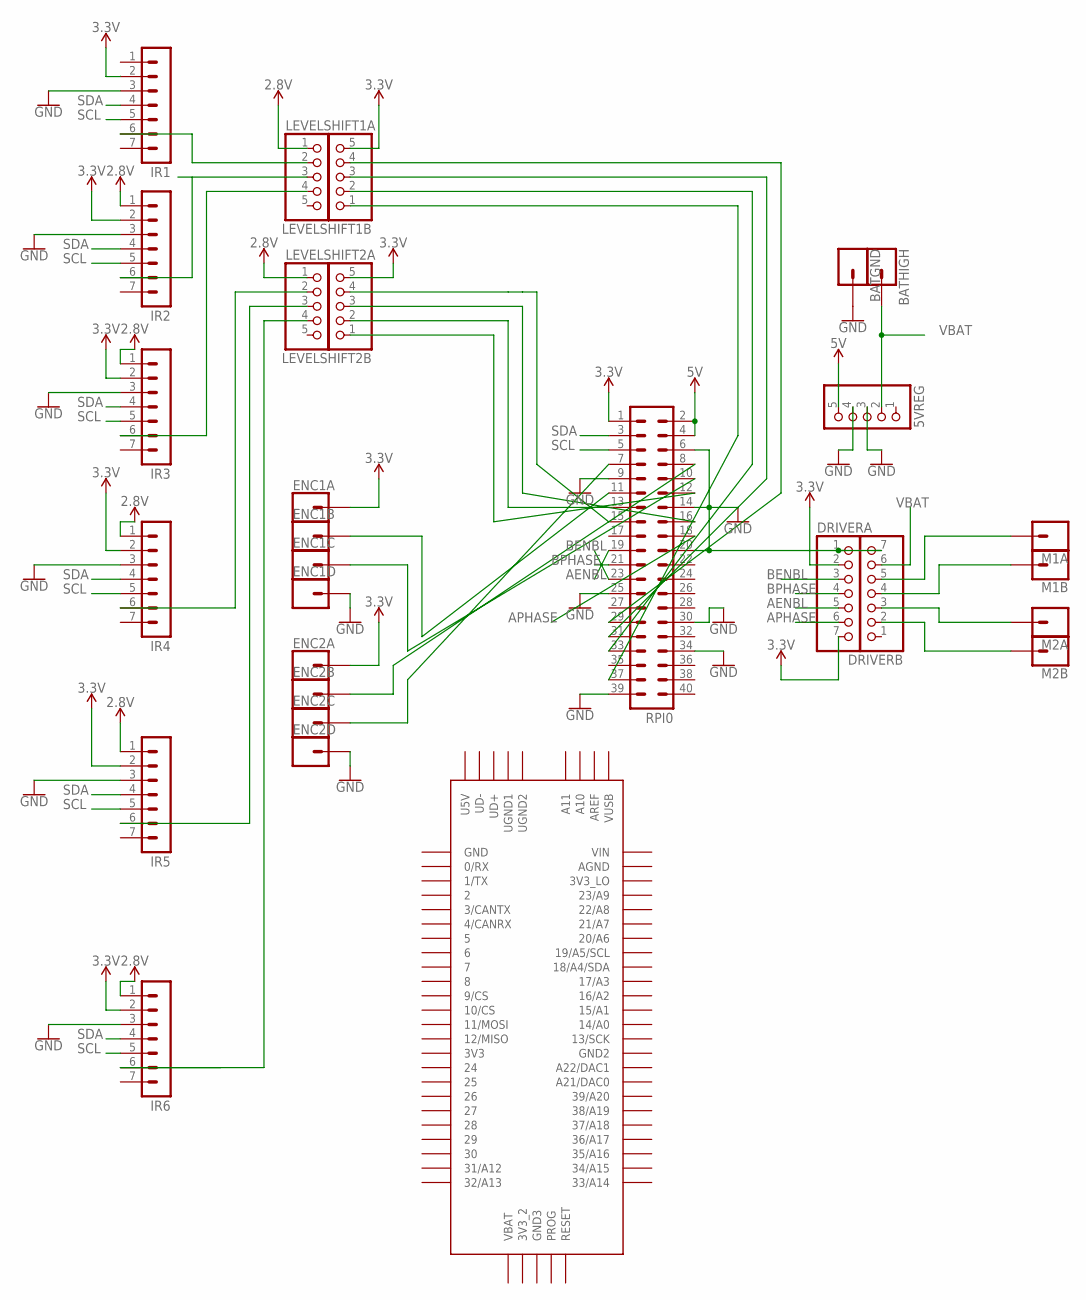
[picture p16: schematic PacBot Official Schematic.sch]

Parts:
5VREG: PINHD-1X5; 1X05
BATGND: CONN_01; 1X01
BATHIGH: CONN_01; 1X01
DRIVERA: PINHD-1X7; 1X07
DRIVERB: PINHD-1X7; 1X07
ENC1A, ENC1B, ENC1C, ENC1D, ENC2A, ENC2B, ENC2C, ENC2D: CONN_01; 1X01
IR1, IR2, IR3, IR4, IR5, IR6: MA07-1
LEVELSHIFT1A, LEVELSHIFT1B, LEVELSHIFT2A, LEVELSHIFT2B: PINHD-1X5; 1X05
M1A, M1B, M2A, M2B: CONN_01; 1X01
RPI0: MA20-2
U$1: TEENSY_3.5/3.6

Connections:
2.8V: IR2.1, IR3.1, IR4.1, IR5.1, IR6.1, LEVELSHIFT1A.1, LEVELSHIFT2A.1
3.3V: DRIVERA.2, DRIVERA.7, ENC1A.1, ENC2A.1, IR1.2, IR2.2, IR3.2, IR4.2, IR5.2, IR6.2, LEVELSHIFT1B.5, LEVELSHIFT2B.5, RPI0.1
5V: 5VREG.5, RPI0.2, RPI0.4
AENBL: DRIVERA.5, RPI0.19
APHASE: DRIVERA.6, RPI0.18
BENBL: DRIVERA.3, RPI0.23
BPHASE: DRIVERA.4, RPI0.21
GND: 5VREG.3, 5VREG.4, BATGND.1, DRIVERA.1, DRIVERB.7, ENC1D.1, ENC2D.1, IR1.3, IR2.3, IR3.3, IR4.3, IR5.3, IR6.3, RPI0.6, RPI0.9, RPI0.14, RPI0.20, RPI0.25, RPI0.30, RPI0.34, RPI0.39
unnamed: ENC1B.1, RPI0.11
unnamed: IR4.6, LEVELSHIFT2A.2
unnamed: LEVELSHIFT2B.2, RPI0.13
unnamed: LEVELSHIFT2B.1, RPI0.12
unnamed: DRIVERB.5, M1A.1
unnamed: DRIVERB.4, M1B.1
unnamed: DRIVERB.3, M2A.1
unnamed: DRIVERB.2, M2B.1
unnamed: ENC1C.1, RPI0.10
unnamed: ENC2B.1, RPI0.8
unnamed: ENC2C.1, RPI0.7
unnamed: IR5.6, LEVELSHIFT2A.3
unnamed: IR6.6, LEVELSHIFT2A.4
unnamed: LEVELSHIFT1B.4, RPI0.29
unnamed: LEVELSHIFT1B.3, RPI0.31
unnamed: LEVELSHIFT1B.2, RPI0.33
unnamed: LEVELSHIFT1B.1, RPI0.37
unnamed: LEVELSHIFT2B.4, RPI0.15
unnamed: LEVELSHIFT2B.3, RPI0.16
unnamed: IR1.6, LEVELSHIFT1A.2
unnamed: IR3.6, LEVELSHIFT1A.4
SCL: IR1.5, IR2.5, IR3.5, IR4.5, IR5.5, IR6.5, RPI0.5
SDA: IR1.4, IR2.4, IR3.4, IR4.4, IR5.4, IR6.4, RPI0.3
VBAT: 5VREG.2, BATHIGH.1, DRIVERB.6

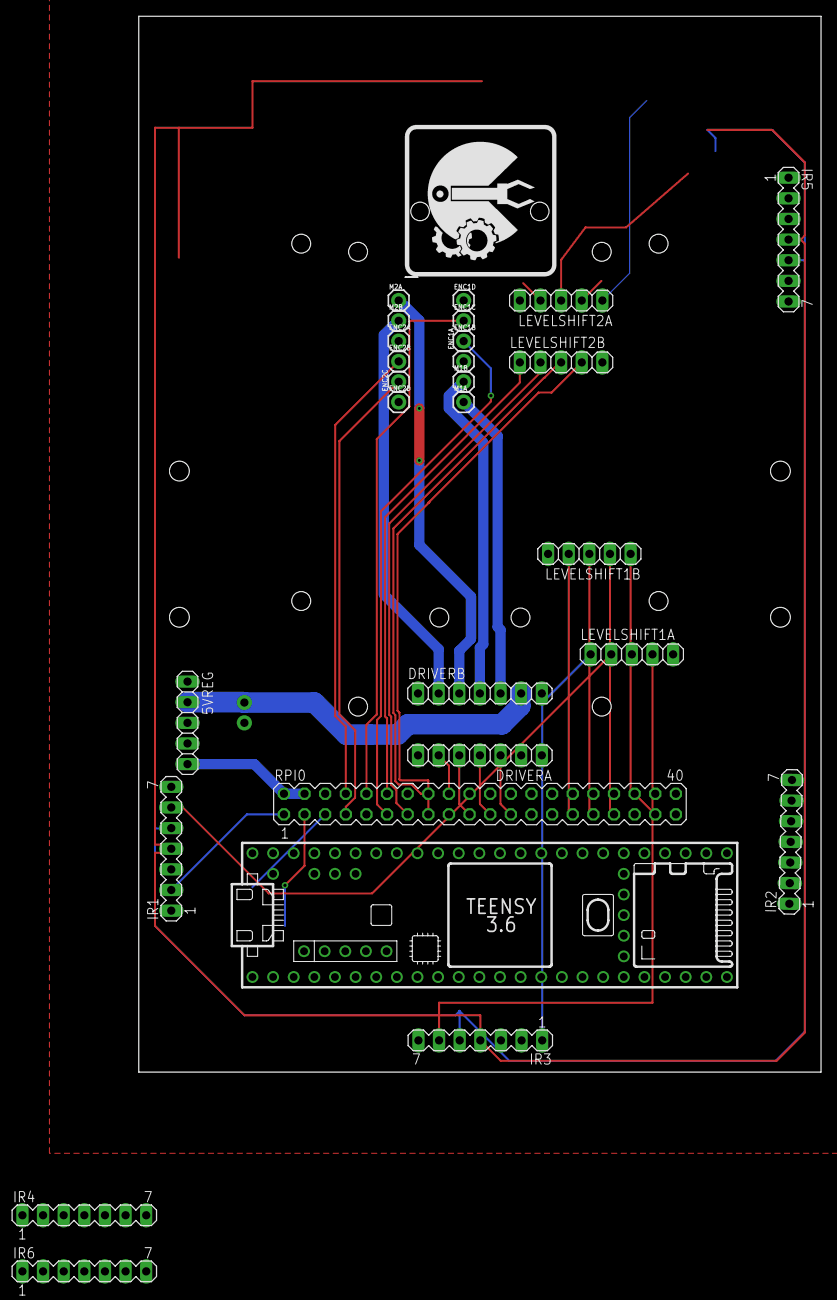
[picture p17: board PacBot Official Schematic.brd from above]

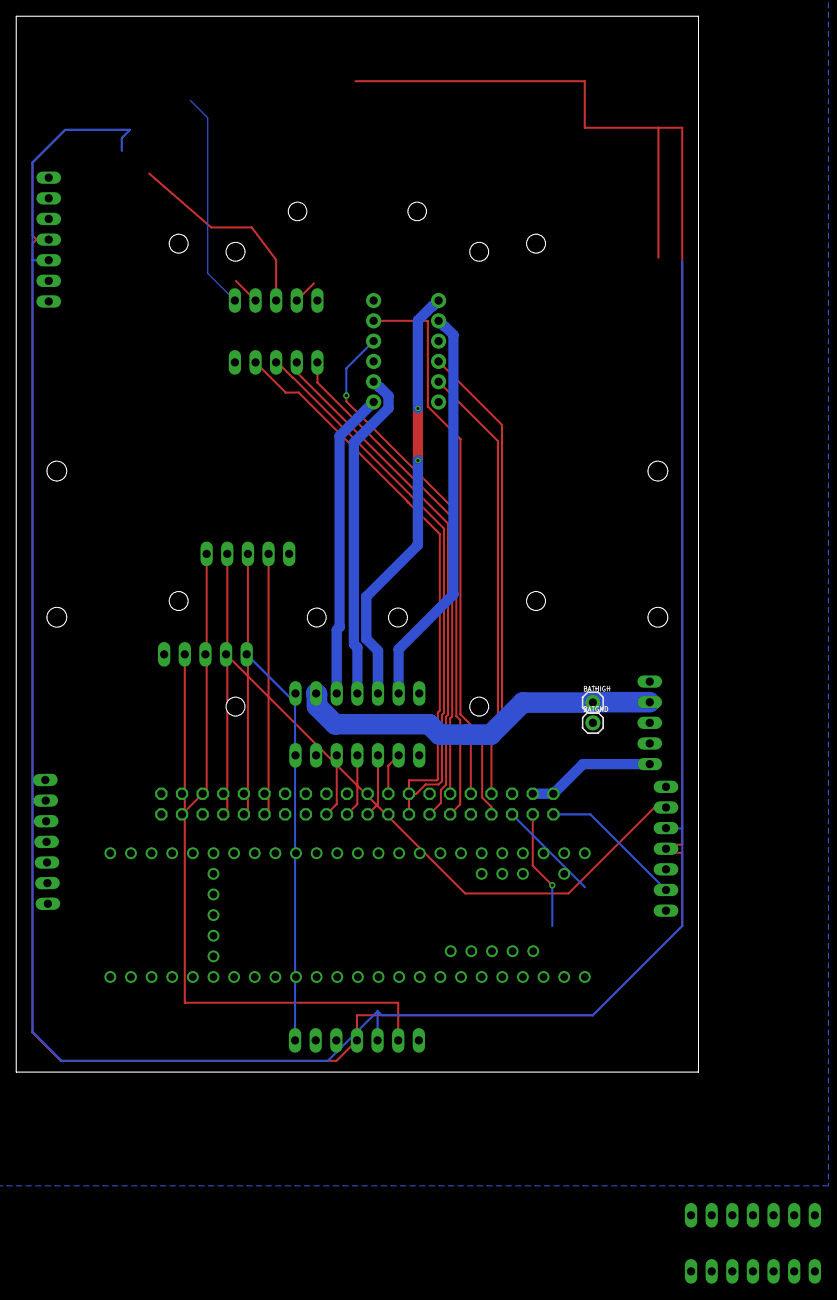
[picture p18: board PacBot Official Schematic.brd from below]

Board: 2 copper layers, 84.0 x 130.0 mm, 29 parts (2 on the bottom side), 32 nets.

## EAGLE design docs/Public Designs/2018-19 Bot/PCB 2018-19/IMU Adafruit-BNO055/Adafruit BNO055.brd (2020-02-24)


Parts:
C1, C2: 22pF; 0805-NO
C3: 0.1uF; 0805-NO
C4: 0.1uF; 0805_10MGAP
C5: 10uF; 0805-NO
C6: 10uF; 0805_10MGAP
D1: 1n4148; SOD-323
FID1, FID2: FIDUCIAL""; FIDUCIAL_1MM
JP1: HEADER-1X676MIL; 1X06_ROUND_76
JP2: HEADER-1X476MIL; 1X04_ROUND_76
Q1, Q2: BSS138; SOT23-WIDE
R3, R4, R5, R6, R7, R10: 10K; 0805-NO
R8, R9: 10K; _0805MP
U1: MIC5225-3.3; SOT23-5
U$2: BNO055
U$29, U$30, U$31, U$32: MOUNTINGHOLE2.5_THICK; MOUNTINGHOLE_2.5_PLATED_THICK
Y1: 32.768kHz; CRYSTAL_8X3.8

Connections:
3.3V: C4.2, C6.1, JP1.2, Q1.1 (G), Q2.1 (G), R6.2, R7.2, R10.2, U1.5 (OUT), U$2.3 (VDD), U$2.4 (NBOOT_LOAD_PIN), U$2.28 (VDDIO)
5.0V: C5.1, JP1.1, R8.2, R9.2, U1.1 (IN), U1.3 (EN)
GND: C1.1, C2.1, C3.1, C4.1, C5.2, C6.2, JP1.3, R3.2, R4.2, R5.2, U1.2 (GND), U$2.2 (GND), U$2.10 (PIN10(GND)), U$2.15 (PIN15(GND)), U$2.16 (PIN16(GND)), U$2.18 (COM2(GND)), U$2.25 (GND)
I2CADDR_3V: JP2.4, R5.1, U$2.17 (COM3/I2C_ADDR)
INT_3V: JP2.3, U$2.14 (INT)
unnamed: C1.2, U$2.27 (XIN32), Y1.P$4 (2)
unnamed: C2.2, U$2.26 (XOUT32), Y1.P$1 (1)
unnamed: C3.2, U$2.9 (CAP)
NRESET_3V: D1.A, R10.1, U$2.11 (NRESET)
PS0_3V: JP2.1, R3.1, U$2.6 (PS0)
PS1_3V: JP2.2, R4.1, U$2.5 (PS1)
RST_5V: D1.C, JP1.6
SCL_3V: Q2.2 (S), R7.1, U$2.19 (COM1/SCL/RX)
SCL_5V: JP1.5, Q2.3 (D), R9.1
SDA_3V: Q1.2 (S), R6.1, U$2.20 (COM0/SDA/TX)
SDA_5V: JP1.4, Q1.3 (D), R8.1



Board: 2 copper layers, 26.7 x 20.3 mm, 31 parts (2 on the bottom side), 16 nets.

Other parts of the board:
U$3: PCBFEAT-REV-040
U$28: ADAFRUIT_TEXT_20MM
U$33: ADAFRUIT_2.5MM

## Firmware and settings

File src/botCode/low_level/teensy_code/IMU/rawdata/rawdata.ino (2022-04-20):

#include <Wire.h>
#include <Adafruit_Sensor.h>
#include <Adafruit_BNO055.h>
#include <utility/imumaths.h>

/* This driver reads raw data from the BNO055

   Connections
   ===========
   Connect SCL to analog 5
   Connect SDA to analog 4
   Connect VDD to 3.3V DC
   Connect GROUND to common ground

   History
   =======
   2015/MAR/03  - First release (KTOWN)
*/

/* Set the delay between fresh samples */
#define BNO055_SAMPLERATE_DELAY_MS (100)

// A few notes from Tom:
// - we were using the wrong I2C bus - the IMU was hooked up to Wire1. This requires changing the Wire library so that Wire1 is defined. Specifically, uncomment #define WIRE_IMPLEMENT_WIRE1 in WireKinetis.h
// - also the sensors need to be calibrated. This website has info for how to do that: https://learn.adafruit.com/adafruit-bno055-absolute-orientation-sensor/device-calibration 

// Check I2C device address and correct line below (by default address is 0x29 or 0x28), make sure the bus is ok too!
//                                   id, address
Adafruit_BNO055 bno = Adafruit_BNO055(-1, 0x28, &Wire1);

/**************************************************************************/
/*
    Arduino setup function (automatically called at startup)
*/
/**************************************************************************/
void setup(void)
{
  Serial.begin(115200);
  Serial.println("Orientation Sensor Raw Data Test"); Serial.println("");

  /* Initialise the sensor */
  if(!bno.begin())
  {
    /* There was a problem detecting the BNO055 ... check your connections */
    Serial.print("Ooops, no BNO055 detected ... Check your wiring or I2C ADDR!");
    while(1);
  }

  delay(1000);

  /* Display the current temperature */
  int8_t temp = bno.getTemp();
  Serial.print("Current Temperature: ");
  Serial.print(temp);
  Serial.println(" C");
  Serial.println("");

  bno.setExtCrystalUse(true);

  Serial.println("Calibration status values: 0=uncalibrated, 3=fully calibrated");
}

/**************************************************************************/
/*
    Arduino loop function, called once 'setup' is complete (your own code
    should go here)
*/
/**************************************************************************/
void loop(void)
{
//  // Possible vector values can be:
//  // - VECTOR_ACCELEROMETER - m/s^2
//  // - VECTOR_MAGNETOMETER  - uT
//  // - VECTOR_GYROSCOPE     - rad/s
//  // - VECTOR_EULER         - degrees
//  // - VECTOR_LINEARACCEL   - m/s^2
//  // - VECTOR_GRAVITY       - m/s^2
//  imu::Vector<3> euler = bno.getVector(Adafruit_BNO055::VECTOR_GYROSCOPE);
//
//  /* Display the floating point data */
//  Serial.print("X: ");
//  Serial.print(euler.x());
//  Serial.print(" Y: ");
//  Serial.print(euler.y());
//  Serial.print(" Z: ");
//  Serial.print(euler.z());
//  Serial.print("\t\t");
//
//  /*
//  // Quaternion data
//  imu::Quaternion quat = bno.getQuat();
//  Serial.print("qW: ");
//  Serial.print(quat.w(), 4);
//  Serial.print(" qX: ");
//  Serial.print(quat.x(), 4);
//  Serial.print(" qY: ");
//  Serial.print(quat.y(), 4);
//  Serial.print(" qZ: ");
//  Serial.print(quat.z(), 4);
//  Serial.print("\t\t");
//  */
//
//  /* Display calibration status for each sensor. */
//  uint8_t system, gyro, accel, mag = 0;
//  bno.getCalibration(&system, &gyro, &accel, &mag);
//  Serial.print("CALIBRATION: Sys=");
//  Serial.print(system, DEC);
//  Serial.print(" Gyro=");
//  Serial.print(gyro, DEC);
//  Serial.print(" Accel=");
//  Serial.print(accel, DEC);
//  Serial.print(" Mag=");
//  Serial.println(mag, DEC);
//
//  delay(BNO055_SAMPLERATE_DELAY_MS);
}

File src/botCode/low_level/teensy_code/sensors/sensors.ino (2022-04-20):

/* 
 * Code for interfacing with encoders and IMU from Teensy.
 * 
 * Encoder code is from this tutorial:
 * http://www.pjrc.com/teensy/td_libs_Encoder.html
 * 
 */

#include <Encoder.h>
#include <Wire.h>
#include <Adafruit_Sensor.h>
#include <Adafruit_BNO055.h>
#include <utility/imumaths.h>


/* Set the delay between fresh samples */
#define SAMPLERATE_DELAY_MS (50)

/* Set up Encoder */
// Change these pin numbers to the pins connected to your encoder.
//   Best Performance: both pins have interrupt capability
//   Good Performance: only the first pin has interrupt capability
//   Low Performance:  neither pin has interrupt capability
Encoder knobLeft(2, 3);
Encoder knobRight(14, 15);
//   avoid using pins with LEDs attached


/* Set up IMU */

// A few notes from Tom:
// - we were using the wrong I2C bus - the IMU was hooked up to Wire1. This requires changing the Wire library so that Wire1 is defined. Specifically, uncomment #define WIRE_IMPLEMENT_WIRE1 in WireKinetis.h
// - also the sensors need to be calibrated. This website has info for how to do that: https://learn.adafruit.com/adafruit-bno055-absolute-orientation-sensor/device-calibration 

// Check I2C device address and correct line below (by default address is 0x29 or 0x28), make sure the bus is ok too!
//                                   id, address
Adafruit_BNO055 bno = Adafruit_BNO055(-1, 0x28, &Wire1);


/* Print to one serial bus */
auto CurrSerial = Serial1;

void setup() {
  delay(10000);           // teensy was turning on too fast
  CurrSerial.begin(38400);

  /* Initialise the IMU */
  if(!bno.begin())
  {
    /* There was a problem detecting the BNO055 ... check your connections */
    CurrSerial.print("Ooops, no BNO055 detected ... Check your wiring or I2C ADDR!");
    while(1);
  }

  delay(1000);

  bno.setExtCrystalUse(true);
}

long positionLeft  = -999;
long positionRight = -999;

String printVectorValues(imu::Vector<3> vector) {
  return String(vector.x()) + " " + String(vector.y()) + " " + String(vector.z()) + "\t";
}

void loop() {

  // Base string
  String base = "";
  
  /*
   * Encoder reading and writing
   * 
   */
  // if a character is sent from the CurrSerial monitor,
  // reset both back to zero.
  if (CurrSerial.available()) {
    CurrSerial.read();
    knobLeft.write(0);
    knobRight.write(0);
  }
  
  long newLeft, newRight;
  newLeft = knobLeft.read();
  newRight = knobRight.read();
  base += String(newLeft);
  base += " ";
  base += String(newRight);
  
  base += "\t";


  /*
   * IMU reading and writing
   * 
   */
   
  // Possible vector values can be:
  // - VECTOR_ACCELEROMETER - m/s^2
  // - VECTOR_MAGNETOMETER  - uT
  // - VECTOR_GYROSCOPE     - rad/s
  // - VECTOR_EULER         - degrees
  // - VECTOR_LINEARACCEL   - m/s^2
  // - VECTOR_GRAVITY       - m/s^2
//  imu::Vector<3> accelerometer = bno.getVector(Adafruit_BNO055::VECTOR_LINEARACCEL);
//  //  base += "LINEARACCEL: ";
//  base += printVectorValues(accelerometer);
//
//  imu::Vector<3> gyroscope = bno.getVector(Adafruit_BNO055::VECTOR_GYROSCOPE);
//  //  base += "GYROSCOPE: ";
//  base += printVectorValues(gyroscope);

  imu::Vector<3> euler = bno.getVector(Adafruit_BNO055::VECTOR_EULER);
  //  base += "EULER: ";
  base += printVectorValues(euler);
  

  /* Display calibration status for each sensor. */
//  uint8_t system, gyro, accel, mag = 0;
//  bno.getCalibration(&system, &gyro, &accel, &mag);
//  //  base += "CALIBRATION: Sys=";
//  base += String(system);
//  //  base += " Gyro=";
//  base += String(gyro);
//  //  base += " Accel=";
//  base += String(accel);
//  //  base += " Mag=";
//  base += String(mag);

  CurrSerial.println(base);

  delay(SAMPLERATE_DELAY_MS);
}

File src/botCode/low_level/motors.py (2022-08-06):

from .motor import Motor, MotorDirection
from .pins import *
from .sensors import Sensors
from .GPIOhelpers import *
from .PID import *
setGPIO()
import time
import signal, sys

from .teensySensors import TeensySensors

from time import sleep


MOTOR_SPEED = 25 
TICKS_CELL = 510   # this is (encoder ticks per axis rev) * (motor gear ratio) * (ratio of cell width to circumference of wheel) - but I think we're missing ticks or something so I did it experimentally


TIME = 3000
KP = 0.4
KI = 0.01
KD = 0.05

class Direction():
    W = 0
    N = 1
    E = 2
    S = 3

class Motors:
    def __init__(self):
        self.teensy_sensors = TeensySensors()
        sleep(2)
        
        self.ir_sensors = Sensors([pins.tof_front,pins.tof_rear,pins.tof_fleft,pins.tof_fright,pins.tof_rleft,pins.tof_rright], ["front", "rear","fleft","fright","rleft","rright"], [0x30,0x31,0x32,0x33,0x34,0x35])
        self._frontIR = self.ir_sensors.sensors["front"]
        self._fleftIR = self.ir_sensors.sensors["fleft"]
        self._frightIR = self.ir_sensors.sensors["fright"]
        self._rearIR = self.ir_sensors.sensors["rear"]
        self._rleftIR = self.ir_sensors.sensors["rleft"]
        self._rrightIR = self.ir_sensors.sensors["rright"]
        sleep(0.5)
        # sometimes intial sensor readings are 0
        self._frontIR.get_distance()
        self._fleftIR.get_distance()
        self._frightIR.get_distance()
        self._rearIR.get_distance()
        self._rleftIR.get_distance()
        self._rrightIR.get_distance()

        self.heading = {Direction.W: 0, Direction.N: 90, Direction.E: 180, Direction.S: 270}
        self.cur_dir = Direction.E

        self.left_motor = Motor("Left", pins.motor_speed_l, pins.motor_direction_l, 0)

        self.right_motor = Motor("Right", pins.motor_speed_r, pins.motor_direction_r, 0)

        self.setpointHeading = 0
        self.inputStraight = 0
        self.PIDHeading = PID(self.inputStraight, self.setpointHeading, KP, KI, KD, DIRECT, Timer)
        self.PIDHeading.set_output_limits(-1*(100 - MOTOR_SPEED), 100 - MOTOR_SPEED)
        self.PIDHeading.set_mode(AUTOMATIC)

        self.setpointTurnHeading = 0
        self.inputTurn = 0
        self.PIDTurn = PID(self.inputTurn, self.setpointHeading, 0.15, 0., 0.0, DIRECT, Timer)
        self.PIDTurn.set_output_limits(-1*MOTOR_SPEED, MOTOR_SPEED)
        self.PIDTurn.set_mode(AUTOMATIC)

        self.reset_heading()

    def read_encoders(self):
        return self.teensy_sensors.get_left_encoder_ticks(), self.teensy_sensors.get_right_encoder_ticks()

    def reset_heading(self):
        current_heading = self.teensy_sensors.get_heading()

        for i in range(4):
            self.heading[(self.cur_dir + i) % 4] = (current_heading + (i * 90)) % 360



    def move_motors(self, left, right):
        if left >= 0:
            self.left_motor.move(MotorDirection.FORWARD, abs(left))
        else:
            self.left_motor.move(MotorDirection.BACKWARD, abs(left))
        if right >= 0:
            self.right_motor.move(MotorDirection.FORWARD, abs(right))
        else:
            self.right_motor.move(MotorDirection.BACKWARD, abs(right))

    def stop(self):
        #print("stopped")
        self.right_motor.stop()
        self.left_motor.stop()
    
    def move_cells(self, cells):
        self.drive_straight(self.heading[self.cur_dir], cells*TICKS_CELL)
    
    def drive_straight(self, heading, ticks):
        #print("drive straight")
        self.teensy_sensors.reset_encoders()
        self.setpointHeading = heading

        factor = ticks/TICKS_CELL
        distance_l, distance_r = 0, 0 
       
        # Cycle front IR  (this is weird and we don't know why)
        self._frontIR.get_distance()
        #print("    ", self._frontIR.get_distance())
        while min(distance_r, distance_l) < ticks:
        #while 1:
            # might wanna add logic to avoid hitting wall

            # logic to add distance for more time to straighten out
            # if abs(distance_l - distance_r) > 140:
            #     print('added: {}'.format(added))
            #     added += 4
            #     ticks += 4
            distance_l, distance_r = self.read_encoders()
            #print("Distance:", distance_l, distance_r)

            self.inputStraight = self.teensy_sensors.get_heading()
            
            # Only undergo PID ever 0.1 second
            last_set = time.time()
            # Compute error
            error = self.compute_heading_error(self.inputStraight, self.setpointHeading)
            self.PIDHeading.compute(error, 0)
            #print("Error:", error, " Pid heading:", self.PIDHeading.output())
            self.move_motors((MOTOR_SPEED + self.PIDHeading.output()), (MOTOR_SPEED - self.PIDHeading.output()))

            #print(self._rleftIR.get_distance(), " ", self._rrightIR.get_distance())

            sleep(0.1)
            if self._frontIR.detectWall(threshold = 60):
                break

        #print("    end drive_straight")

    def reverse(self, cells):
        self.reverse_direction()
        self.move_cells(cells)

    def back(self):
        if(self._rearIR.get_distance() > 25 and self._rleftIR.get_distance()> 10 and self._rrightIR.get_distance() > 10):
            print("back")
            self.move_ticks(-TICKS_CELL/4, -TICKS_CELL/4)
        else:
            print("not back")
 

    def turn_around(self):
        self.cur_dir = (self.cur_dir + 2) % 4
        self.turn_to_direction(self.heading[self.cur_dir])

    def compute_heading_error(self, cur, des):
        return (cur - des + 540) % 360 - 180

    def turn_to_direction(self, heading):
        self.inputTurn = self.compute_heading_error(self.teensy_sensors.get_heading(), heading)
        self.setpointTurnHeading = 0
        while abs(self.inputTurn) > 1:
            self.inputTurn = self.compute_heading_error(self.teensy_sensors.get_heading(), heading)
            self.PIDTurn.compute(self.inputTurn, self.setpointTurnHeading)
            self.move_motors(self.PIDTurn.output(), -self.PIDTurn.output())
        self.stop()
    
    def follow_heading_till_clear(self, irSensor, heading, direction=1):
        self.setpointHeading = heading
        
        # Cycle front and back IR  (this is weird and we don't know why)
        self._frontIR.get_distance()
        self._rearIR.get_distance()

        
        start_time = time.time()
        while (irSensor.detectWall() and ((time.time() - start_time < 1))):
            self.inputStraight = self.teensy_sensors.get_heading()
            error = self.compute_heading_error(self.inputStraight, self.setpointHeading)
            self.PIDHeading.compute(error, 0)
            self.move_motors(direction * (MOTOR_SPEED - 10 + self.PIDHeading.output()), direction * (MOTOR_SPEED - 10 - self.PIDHeading.output()))
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

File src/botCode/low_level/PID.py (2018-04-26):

""" PID library
Converted from arduino library: http://playground.arduino.cc/Code/PIDLibrary 
Explanation at: http://brettbeauregard.com/blog/2011/04/improving-the-beginners-pid-introduction/
"""
AUTOMATIC = 1
MANUAL = 0
DIRECT = 1
REVERSE = 0
class PID:
    # constants
    AUTOMATIC = 1
    MANUAL = 0
    DIRECT = 1
    REVERSE = 0

    def __init__(self, inp, setpoint, kp, ki, kd, controller_direction, timer):
        self._input = inp
        self._setpoint = setpoint
        self._timer = timer()
        self._in_auto = False
        self._output = 0
        self._controller_direction = controller_direction
        self._last_input = 0

        # default output limits
        self.set_output_limits(0, 255)

        # default controller sample time is 0.1 seconds
        self._sample_time = 100

        self.set_controller_direction(self._controller_direction)

        self.set_tunings(kp, ki, kd)

        self._last_time = self.millis() - self._sample_time

    def compute(self, my_input, my_setpoint):
        """ compute is called evertime loop excutes.
        It decides for itself whether new output needs to be computed.
        Returns True when output is computed and false otherwise.
        """ 
        if not self._in_auto:
            return False

        self._input = my_input
        self._setpoint = my_setpoint

        now = self.millis()
        time_change = now - self._last_time

        if time_change < self._sample_time:
            return False

        # compute all working error variables
        error = self._setpoint - self._input
        self._I_term += self._ki * error
        
    
        if self._I_term > self._out_max:
            self._I_term = self._out_max
        elif self._I_term < self._out_min:
            self._I_term = self._out_min

        d_input = self._input - self._last_input

        # compute PID output
        self._I_term = 0
        output = self._kp * error + self._I_term - self._kd * d_input

        if output > self._out_max:
            output = self._out_max
        elif output < self._out_min:
            output = self._out_min

        self._output = output

        # update relevant variables
        self._last_input = self._input
        self._last_time = now

        return True

    def output(self):
        return self._output

    def set_tunings(self, kp, ki, kd):
        """ Allows the controllers dynamic performance to be adjusted."""
        if kp < 0 or ki < 0 or kd < 0:
            return

        self._disp_kp = kp
        self._disp_ki = ki
        self._disp_kd = kd

        sample_time_in_sec = self._sample_time / 1000

        self._kp = kp
        self._ki = ki * sample_time_in_sec
        self._kd = kd / sample_time_in_sec

        if self._controller_direction == REVERSE:
            self._kp = - self._kp
            self._ki = - self._ki
            self._kd = - self._kd

    def set_sample_time(self, new_sample_time):
        """ sets the period, in milliseconds, at which the calculation is performed. """
        if new_sample_time <= 0:
            return

        ratio = new_sample_time / self._sample_time
        self._ki *= ratio
        self._kd /= ratio
        self._sample_time = new_sample_time

    def set_output_limits(self, min, max):
        if min >= max:
            return

        self._out_min = min
        self._out_max = max

        if self._in_auto:
            if self._output > self._out_max:
                self._output = self._out_max
            elif self._output < self._out_min:
                self._output = self._out_min

            if self._I_term > self._out_max:
                self._I_term = self._out_max
            elif self._I_term < self._out_min:
                self._I_term = self._out_min

    def set_mode(self, mode):
        """ Allows the controller mode to be set to MANUAL or AUTOMATIC.
        When mode if changed from manual to auto, the controller is automatically (re)initialized.
        """
        new_auto = (mode == AUTOMATIC)

        if  new_auto and not self._in_auto:
            self._intialize()

        self._in_auto = new_auto

    def _intialize(self):
        """ Handles mode change from manual to auto. """
        self._I_term = 0
        self._last_input = self._input

        if self._I_term > self._out_max:
            self._I_term = self._out_max
        elif self._I_term < self._out_min:
            self._I_term = self._out_min

    def set_controller_direction(self, direction):
        """ DIRECT: +output -> +input
        REVERSE: +output -> -input
        """
        if self._in_auto and direction != self._controller_direction:
            self._kp = - self._kp
            self._ki = - self._ki
            self._kd = - self._kd

        self._controller_direction = direction

    def get_kp(self):
        return self._disp_kp

    def get_ki(self):
        return self._disp_ki

    def get_kd(self):
        return self._disp_kd

    def get_mode(self):
        if self._in_auto:
            return AUTOMATIC
        else:
            return MANUAL

    def get_direction(self):
        return self._controller_direction

    def millis(self):
        return self._timer.millis()

        

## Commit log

2017-04-16 working on motortest.c
2017-04-16 motortest.c failed
2017-04-22 better print
2017-04-22 remove print
2017-09-11 fixed code + added terminal printer
2017-09-17 added communication between terminal printer and game engine
2017-09-17 improved documentation, refactored socket wrapper into its own file
2017-09-17 fixed terminal printer
2017-09-20 Some camera vision shims
2017-10-08 swapped to robomodules framework
2017-10-09 add timer
2017-10-18 implemented tick with frequencey 2hz in order to prevent Pacbot from flying aroudn the course
2017-10-28 Heuristic high level (#23)
    * heuristic part 2
    * Tested and tuned heuristic Phase II
    * updated heuristic high level, to account for all ghosts, need to tune ghost_cutoff
    * fixed bug with considering ghosts beyond the cutoff
    * Removed print statements
2018-01-28 fix camera reader vol1
2018-04-26 Low level (#26)
    * added the initial codes for super low level control
    * cleanup
    * work on lowLevelModule
    * GPIO helpers updated to add millis function. PID library added
    * motor.py modified to supoort speed sepcification. motorTest modified correspondingly. PID.py modified to add output() module. WallFollowTest added. The scope of variables need to determined while testing.
    * fixed indentation in wallFollowTest
    * changes imported from pi
    * syntax error fixed
    * sensor library moved
    * correct sensor library
    * variable change
    * variable change
    * changes impoted from pi
    * changes to print statements and tof_sensor
    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
    [GPIOhelpers.py, PID.py, ST_VL6180X.py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]
2019-10-29 Updated Docs
    [1classic_arena_pacbot.SLDPRT]
2020-01-27 Added PCB Files
    [PacBot_2019-2020-B_Cu.gbr, PacBot_2019-2020-B_Mask.gbr, PacBot_2019-2020-B_SilkS.gbr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]
2020-10-24 copying 2019-2020 into 2020-2021
    [PacBot_2019-2020-B_Cu.gbr, PacBot_2019-2020-B_Mask.gbr, PacBot_2019-2020-B_SilkS.gbr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]
2020-10-28 adding deque and pid stuff
2020-10-28 more progress on pid and deque
2020-10-28 seems like a working pid class to me. Untested though
2020-10-28 adding motor and tof templates, no functionality yet
2020-10-28 adding imu file
2021-02-01 try running this to see the error: g++ -std=c++14 -c -Wall utils/conversions.cpp dataTypes/deque.cpp controllers/pid.cpp
2021-10-27 restructured code base for 2021-2022
    [PacBot_2019-2020-B_Cu.gbr, PacBot_2019-2020-B_Mask.gbr, PacBot_2019-2020-B_SilkS.gbr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]
2021-11-24 shuffling documentation
    [1classic_arena_pacbot.SLDPRT, Adafruit BNO055.brd, Adafruit BNO055.sch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]
2022-01-02 remove folders
    [1classic_arena_pacbot.SLDPRT, Adafruit BNO055.brd, Adafruit BNO055.sch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]
2022-01-26 bot PCB added
    [PacBot_2021-2022.sch, PacBot_board_outline.dxf, PacbotPCB.DXF]
2022-01-26 removed PCB dir
    [PacBot_2021-2022.sch, PacBot_board_outline.dxf, PacbotPCB.DXF]
2022-02-09 shuffle public design docs
    [Adafruit BNO055.brd, Adafruit BNO055.sch, PacBot Official Schematic 2018-2019.brd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]
2022-02-09 Revert "shuffle public design docs"
    This reverts commit 1f18fdc1b2d93b0dda7e0a9332dcd78fc0c3774f.
    [Adafruit BNO055.brd, Adafruit BNO055.sch, PacBot Official Schematic 2018-2019.brd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]
2022-02-09 shuffle docs
    [Adafruit BNO055.brd, Adafruit BNO055.sch, PacBot Official Schematic 2018-2019.brd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]
2022-02-09 2020-21 README added
    [PacBot_2019-2020-B_Cu.gbr, PacBot_2019-2020-B_Mask.gbr, PacBot_2019-2020-B_SilkS.gbr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]
2022-04-20 separating low and upper parts of game board

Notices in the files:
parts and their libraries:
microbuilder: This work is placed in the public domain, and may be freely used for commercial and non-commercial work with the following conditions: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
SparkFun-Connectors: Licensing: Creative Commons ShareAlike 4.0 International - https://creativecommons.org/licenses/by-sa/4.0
